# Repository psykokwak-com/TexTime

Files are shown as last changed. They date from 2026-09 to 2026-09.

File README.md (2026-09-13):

# TexTime

TexTime is a DIY word clock: a steel faceplate with the letters cut out, a matrix of
addressable RGB LEDs behind it, and an ESP8266 that tells the time in words, in French
or English. It comes in two sizes, a 40 × 40 cm clock that can be 3D-printed and
assembled at home, and a 100 × 100 cm wall piece built on laser-cut MDF.

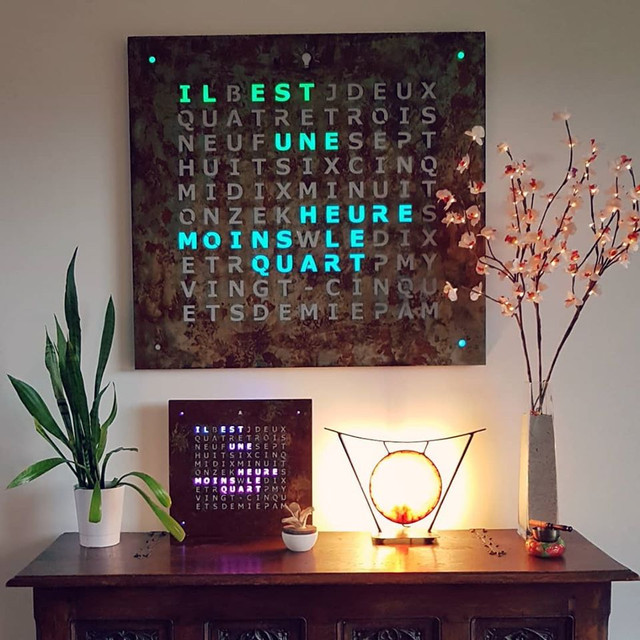
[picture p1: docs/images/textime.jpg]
TexTime


Everything needed to build one is in this repository: the firmware, the electronics,
the mechanical files, the bills of materials and the build guides.

**A word of caution.** This repository gathers, after the fact, the pieces of a project
that is several years old: firmware, design files, notes and photos brought together
into one place. Some of the information may be inaccurate or out of date, in particular
supplier references, part availability, prices and online tools. Check before ordering,
and treat the guides as a starting point rather than a guarantee.

## What is in here

| Folder | Content |
|---|---|
| [`firmware/TexTime`](firmware/TexTime) | Arduino sketch for the ESP8266 (NodeMCU). Web interface, MQTT, NTP, scheduler, animations, games. Pre-built binaries are on the [releases page](../../releases). |
| [`hardware/electronics/pcb-multi-ledstripe`](hardware/electronics/pcb-multi-ledstripe) | The control board, common to both sizes when the LEDs are a strip: schematic, gerbers, bill of materials, JLCPCB SMT files. |
| [`hardware/electronics/pcb-40x40-integrated`](hardware/electronics/pcb-40x40-integrated) | The 40 × 40 integrated board: one PCB carrying the 114 WS2813 LEDs and the control electronics, instead of a cut-up strip. Both boards can be made at [JLCPCB](https://jlcpcb.com/) for a few euros from the gerber files. |
| [`hardware/mechanical/40x40`](hardware/mechanical/40x40) | Faceplate DXF, 3D-printed frame STL (one piece or four parts), back cover DXF. |
| [`hardware/mechanical/100x100`](hardware/mechanical/100x100) | Faceplate DXF and the three laser-cut MDF layers of the LED support. |
| [`bom`](bom) | Bill of materials for each size, with supplier references (French). |
| [`docs`](docs) | Build guides (French). |

## The two sizes

|  | 40 × 40 | 100 × 100 |
|---|---|---|
| Faceplate | Steel S235, 1 mm, laser cut, held by 24 magnets | Steel S235, 1 mm, laser cut |
| Structure | 3D-printed PLA frame, one piece or four | Five glued laser-cut MDF plates (3 + 3 × 10 + 3 mm), no frame |
| LEDs | Strip, 30 LED/m, 114 LEDs, or the integrated board | Strip, two LEDs per letter, folded at the end of each row |
| Control | Control board with the strip; with the integrated board it is already on it, nothing extra to make | Control board |
| Power | 5 V 5 A | 5 V 10 A |
| Firmware "Clock type" | `40x40@1` | `100x100@3` (folded strip), `@2` or `@1` (cut and joined) |

For the strip, SK6812 RGBW 5 V is the better choice today: better quality than
WS2812/WS2813, and its dedicated white LED is used for white text. WS2813 still works.
The strip type is selected in the settings, "LED type".

## Building one

1. Read the build guide: [`docs/build-guide-40x40.md`](docs/build-guide-40x40.md) or [`docs/build-guide-100x100.md`](docs/build-guide-100x100.md).
2. Order the parts from the bill of materials in [`bom`](bom).
3. Flash the latest firmware from the [releases](../../releases), or build it yourself, see [`firmware/TexTime/README.md`](firmware/TexTime/README.md).
4. On first boot the clock opens a `TexTime-xxxx` WiFi network; connect to it, open `http://192.168.1.1/` and enter your WiFi settings.

This is a personal project, shared so that others can build their own. It comes without
any guarantee.

## License

Everything here, firmware, hardware files, documentation and images, is released under
[CC0 1.0 Universal](LICENSE): public domain, no rights reserved, no attribution
required. Use it, change it, sell it. TexTime is itself a reproduction of an existing
word-clock design, and no ownership is claimed on the idea.

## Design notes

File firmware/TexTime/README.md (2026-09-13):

# TexTime

TexTime project is a DIY word clock project based on an ESP8266 MCU and WS2813 LEDs. 
The clock displays time using illuminated words rather than traditional digits, with several features like : 
- Support for multiple languages (French and English).
- Web interface configuration
- MQTT support
- Automatic NTP time synchronization with timezone and daylight saving
- Multiple matrix configurations (40x40, 100x100 variants)
- Selectable LED type: WS2812/WS2813 (default), SK6812 RGB and RGBW, WS2811, APA106
- Animation effects: Blink, Fire, Matrix, Rainbow, and more
- Color randomization modes
- Automatic brightness based on ambient light
- OTA firmware update

TexTime

## 👷 Build Requirements

To build this code, you need the following Arduino libraries:
- **NeoPixelBus by Makuna**: https://github.com/Makuna/NeoPixelBus
- **Rtc by Makuna**: https://github.com/Makuna/Rtc

The hardware (electronics, mechanical files, bills of materials) and the build guides
are in the parent folders of this repository.

## 🤖 Development Credits

The modern web interface redesign and optimization were implemented by **Claude AI** (Anthropic), providing:
- Complete frontend/backend refactoring
- Modern responsive design implementation
- Performance optimization for ESP8266
- Enhanced user experience features
- Comprehensive code cleanup and documentation

---

*TexTime continues to evolve with modern web technologies while maintaining its DIY spirit and Arduino compatibility.*

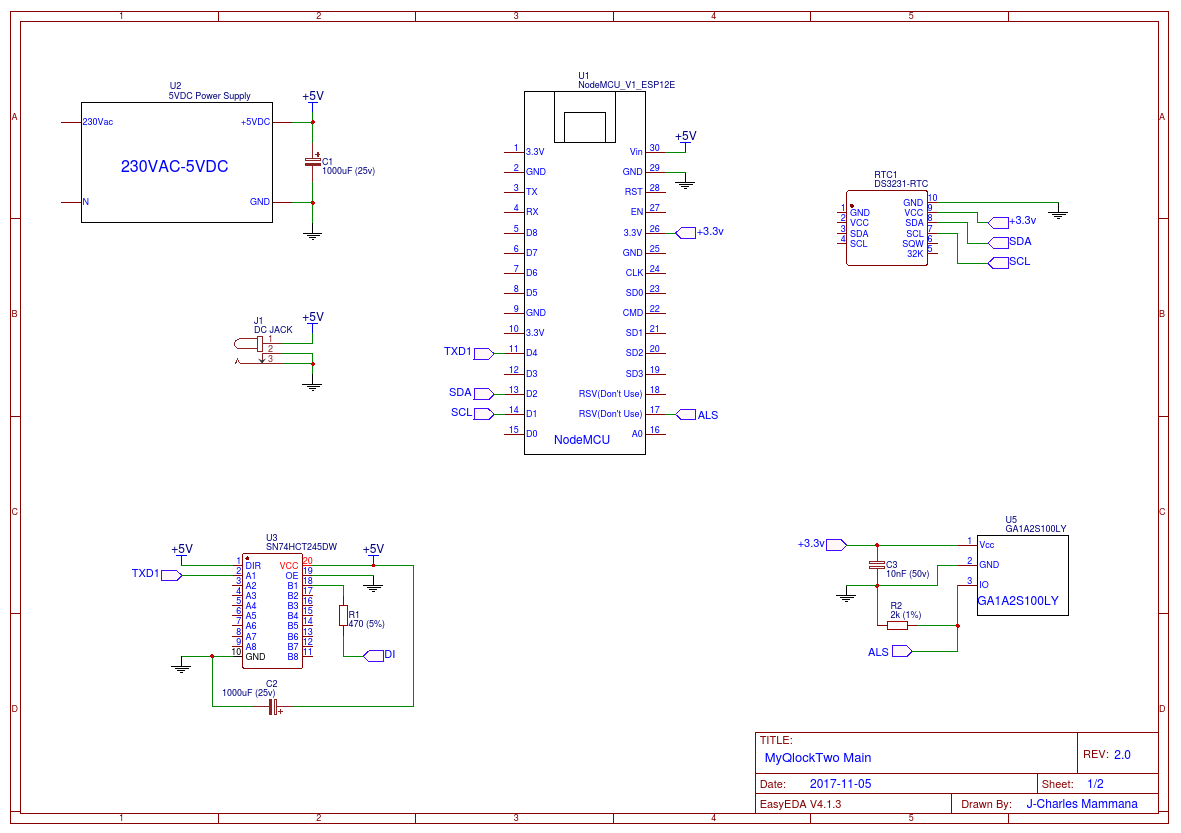
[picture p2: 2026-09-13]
hardware/electronics/pcb-40x40-integrated/schematic-control.png

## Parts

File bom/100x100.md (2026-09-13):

# Nomenclature — TexTime 100 × 100

L'horloge d'un mètre : une façade acier de 90 × 90 cm sur un sandwich de plaques de MDF
collées, sans cadre. Les fichiers de fabrication sont dans
[`hardware/mechanical/100x100`](../hardware/mechanical/100x100), l'électronique est la
même que pour le 40 × 40 en version bandeau. Les quantités de bandeau dépendent du
câblage choisi, voir plus bas.

## Mécanique

| Pièce | Qté | Fichier | Fabrication |
|---|---|---|---|
| Façade acier S235, 1 mm, découpe laser | 1 | [`faceplate-steel-s235-1mm.dxf`](../hardware/mechanical/100x100/faceplate-steel-s235-1mm.dxf) | Sous-traitant découpe laser grand format |
| Plaque avant, MDF 3 mm | 1 | [`led-support-layer0-mdf-3mm.dxf`](../hardware/mechanical/100x100/led-support-layer0-mdf-3mm.dxf) | Découpe laser grand format |
| Plaque intermédiaire, MDF 10 mm | 3 | [`led-support-layer1-mdf-10mm.dxf`](../hardware/mechanical/100x100/led-support-layer1-mdf-10mm.dxf) | Idem, trois exemplaires du même dessin |
| Plaque arrière, MDF 3 mm | 1 | [`led-support-layer2-mdf-3mm.dxf`](../hardware/mechanical/100x100/led-support-layer2-mdf-3mm.dxf) | Idem |
| Vue d'ensemble des plaques assemblées | | [`led-support-assembly.stl.zip`](../hardware/mechanical/100x100/led-support-assembly.stl.zip) | Pour visualiser, pas pour fabriquer |
| Colle à bois | | | Collage des cinq plaques |
| Aimants néodyme N52 | Un lot | | Aliexpress |
| Diffuseur (papier sulfurisé ou calque) | | | |

## Électronique

| Pièce | Qté | Détail |
|---|---|---|
| Carte de contrôle et ses composants | 1 | Identique au 40 × 40, voir [`bom/40x40.md`](40x40.md), section Carte de contrôle |
| Bandeau SK6812 RGBW 5 V, 30 LED/m, IP30 | 2 rouleaux de 5 m | Recommandé. Un bandeau WS2813 convient aussi. Voir le nombre de LED ci-dessous |
| Câble 4 fils | 5 m | Seulement pour les câblages à sections coupées |
| Alimentation 5 V 10 A | 1 | Deux fois plus de LED qu'en 40 × 40 |
| Pile CR2032 | 1 | Pour la RTC |

## Nombre de LED selon le câblage

Le firmware connaît trois câblages pour cette taille, choisis dans « Type d'horloge ».
Le bandeau parcourt les lignes en boustrophédon.

| Type d'horloge | Câblage | LED par lettre | LED au total | Bandeau à 30 LED/m |
|---|---|---|---|---|
| `100x100@3` | Bandeau plié en bout de ligne, sans découpe ni raccord, 4 LED sacrifiées par pli. Recommandé | 2 | 262 | 8,8 m |
| `100x100@2` | Bandeau coupé à chaque ligne, sections raccordées par câble, 2 LED inutilisées entre deux lignes | 2 | 244 | 8,2 m |
| `100x100@1` | Bandeau coupé à chaque ligne, sections raccordées par câble, 1 LED inutilisée entre deux lignes | 1 | 234 | 7,8 m |

Le détail des index de chaque lettre est dans
[`LedStrip.h`](../firmware/TexTime/LedStrip.h), classes `LedConfiguration100x100_1`, `_2` et `_3`.

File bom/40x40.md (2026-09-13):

# Nomenclature — TexTime 40 × 40

Tout ce qu'il faut acheter ou faire fabriquer pour une horloge de 40 cm. Les fichiers
de fabrication sont dans [`hardware/`](../hardware). Les références Aliexpress changent
souvent : chercher l'équivalent si une option n'existe plus.

## Mécanique

| Pièce | Qté | Fichier | Fabrication |
|---|---|---|---|
| Façade acier S235, 1 mm, découpe laser ou jet d'eau | 1 | [`faceplate-steel-1mm.dxf`](../hardware/mechanical/40x40/faceplate-steel-1mm.dxf) | Sous-traitant découpe laser : John Steel, Laserhub, société locale (cherchez sur google)… Variante 2 mm : [`faceplate-steel-2mm.dxf`](../hardware/mechanical/40x40/faceplate-steel-2mm.dxf) |
| Structure imprimée 3D, PLA, remplissage 20 %, couche 0,3 mm | 1 | [`frame-3dprint-one-piece.stl.zip`](../hardware/mechanical/40x40/frame-3dprint-one-piece.stl.zip) ou les quatre parties [`frame-3dprint-part1..4.stl`](../hardware/mechanical/40x40) | Plateau 40 × 40 cm minimum pour la version une pièce, sinon les quatre parties et de la colle PVC |
| Capot arrière MDF 3 mm, découpe laser | 1 | [`back-cover-mdf-3mm.dxf`](../hardware/mechanical/40x40/back-cover-mdf-3mm.dxf) | Artisan laser, ou impression 3D avec [`back-cover.stl`](../hardware/mechanical/40x40/back-cover.stl) |
| Aimants néodyme N52, cylindriques Ø 12 × 3 mm | 24 | | Aliexpress |
| Papier sulfurisé (diffuseur) | 1 feuille 38 × 38 cm | | Cuisine |

## Carte de contrôle — `pcb-multi-ledstripe`

Une seule carte, qui pilote le bandeau de LED. Fichiers dans
[`hardware/electronics/pcb-multi-ledstripe`](../hardware/electronics/pcb-multi-ledstripe).

| Pièce | Repère | Qté | Référence | Fournisseur |
|---|---|---|---|---|
| PCB, 2 couches, blanc conseillé | | 1 (min. 5 à la commande) | [`gerber.zip`](../hardware/electronics/pcb-multi-ledstripe/gerber.zip) | [JLCPCB](https://jlcpcb.com/) : envoyer le zip, les 5 pièces reviennent à quelques euros |
| NodeMCU V3 (ESP-12E) | U1 | 1 | LCSC C111436 | Aliexpress, LCSC |
| Module RTC DS3231 avec AT24C32, montage vertical | RTC1 | 1 | | Aliexpress |
| Pile CR2032 pour la RTC | | 1 | | |
| SN74HCT245N, DIP20 | U3 | 1 | LCSC C133640 | LCSC, RS |
| Condensateur 1000 µF 25 V, Ø 10 mm | C1, C2 | 2 | LCSC C10750 | LCSC, Aliexpress |
| Condensateur 47 µF | C3 | 1 | Nichicon UTS0J470MDD, LCSC C308860 | LCSC |
| Résistance 470 Ω 1 % axiale | R1 | 1 | LCSC C58592 | LCSC, RS |
| Résistance 2,5 kΩ 1 % axiale | R2 | 1 | LCSC C172683 | LCSC, RS |
| Capteur de lumière BH1620FVC-TR, CMS WSOF-5 | U4 | 1 | ROHM, LCSC C84991 | LCSC. Seul composant CMS, soudé côté cuivre ; JLCPCB peut le poser avec [`jlcpcb-smt-bom.csv`](../hardware/electronics/pcb-multi-ledstripe/jlcpcb-smt-bom.csv) et [`jlcpcb-smt-cpl.csv`](../hardware/electronics/pcb-multi-ledstripe/jlcpcb-smt-cpl.csv) |
| Bornier vissable 2 pôles 5,08 mm | CN2 | 1 | Phoenix MKDS3/2-5.08, LCSC C89120 | LCSC, Aliexpress |
| Bornier vissable 4 pôles 5,08 mm | JP1 | 1 | Phoenix MKDS3/4-5.08, LCSC C90087 | LCSC, Aliexpress |

La liste au format CSV, telle qu'exportée d'EasyEDA :
[`bom.csv`](../hardware/electronics/pcb-multi-ledstripe/bom.csv).

## LED — option 1, le bandeau

| Pièce | Qté | Détail |
|---|---|---|
| Bandeau SK6812 RGBW 5 V, 30 LED/m, IP30 | 4 m (114 LED) | Recommandé : meilleure qualité que le WS2813, LED blanche dédiée. Aliexpress, option « 4m 30 IP30 » ou « 5m 30 IP30 ». Un bandeau WS2813 convient aussi |
| Câble 4 fils pour relier les sections | 5 m | Aliexpress, option « 5m 4pin cable » |
| Étain, flux, scotch | | Pour les 24 raccords |

## LED — option 2, la carte intégrée `pcb-40x40-integrated`

Remplace à la fois le bandeau et la carte `pcb-multi-ledstripe` : les 114 LED et toute
l'électronique de contrôle sont sur la même carte, il n'y a pas de carte de contrôle à
fabriquer en plus. Fichiers dans
[`hardware/electronics/pcb-40x40-integrated`](../hardware/electronics/pcb-40x40-integrated).

| Pièce | Qté | Détail |
|---|---|---|
| PCB intégré | 1 (min. 5) | [`gerber.zip`](../hardware/electronics/pcb-40x40-integrated/gerber.zip), à faire fabriquer chez [JLCPCB](https://jlcpcb.com/) pour pas cher |
| LED WS2813B-B | 114, prendre 120 | Le suffixe **B-B** compte : c'est le brochage du PCB. TME ou LCSC de préférence |
| Bornier vissable 4 pôles 5,08 mm | 1 | Aliexpress, option « 128-5.08-2P » × 2 |
| Composants de contrôle | 1 jeu | Les mêmes que ceux de la carte de contrôle ci-dessus, soudés sur la carte intégrée, sans le PCB `pcb-multi-ledstripe`. Voir [`schematic-control.png`](../hardware/electronics/pcb-40x40-integrated/schematic-control.png) |

## Alimentation

| Pièce | Qté | Détail |
|---|---|---|
| Bloc secteur 5 V 5 A, prise EU | 1 | Aliexpress. L'horloge tire jusqu'à 5 A |
| Embase DC femelle DC-022B 5,5 × 2,1 mm | 1 | Aliexpress, se fixe sur la structure |

## Visserie

| Pièce | Qté | Usage |
|---|---|---|
| Vis M3 × 12 tête fraisée, inox | 4 | PCB de contrôle sur la structure |
| Écrou nylstop M3, inox | 4 | Idem |
| Vis à bois 3 × 12 | 11 | Capot arrière |
| Colle PVC (gouttières) | | Assemblage des quatre parties de la structure |
| Pistolet à colle | | Aimants, câble d'alimentation |

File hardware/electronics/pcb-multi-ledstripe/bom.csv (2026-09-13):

ID | Name | Designator | Footprint | Quantity | Manufacturer Part | Manufacturer | Supplier | Supplier Part
1 | NodeMCU_V1_ESP12E | U1 | MY NODEMCU | 1 | NodeMCU-32SLua | Ai-Thinker | LCSC | C111436
2 | 1000uF (25v) | C1,C2 | CAP-D10.0XF5.0 | 2 | 1000uF 25V | ValuePro | LCSC | C10750
3 | DS3231-RTC | RTC1 | DS3231-RTC-24C32-EEPROM VERTICAL SIPPY | 1 | ?
4 | SN74HCT245N | U3 | DIP20 | 1 | SN74HCT245N | Texas Instruments | LCSC | C133640
5 | M04 | JP1 | MKDS3/4-5.08 | 1 | MKDS3/4-5.08 | Phoenix Contact | LCSC | C90087
6 | 470 (1%) | R1 | AXIAL-0.3 | 1 | MFR0W4F4700A50 | UniOhm | LCSC | C58592
7 | 2.5k (1%) | R2 | AXIAL-0.3 | 1 | RN16T52501F | TA-I Tech | LCSC | C172683
8 | BH1620FVC-TR | U4 | WSOF-5 | 1 | BH1620FVC-TR | ROHM | LCSC | C84991
9 | MKDS3/2-5.08 | CN2 | MKDS3/2-5.08 | 1 | MKDS3/2-5.08 | Phoenix Contact | LCSC | C89120
10 | 47uF | C3 | CAP-5*7 | 1 | UTS0J470MDD | Nichicon | LCSC | C308860

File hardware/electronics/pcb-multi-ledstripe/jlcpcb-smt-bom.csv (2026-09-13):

ID | Name | Designator | Footprint | Quantity | Manufacturer Part | Manufacturer | Supplier | Supplier Part
0 | BH1620FVC-TR | U4 | WSOF-5 | 1 | BH1620FVC-TR | ROHM | LCSC | C84991

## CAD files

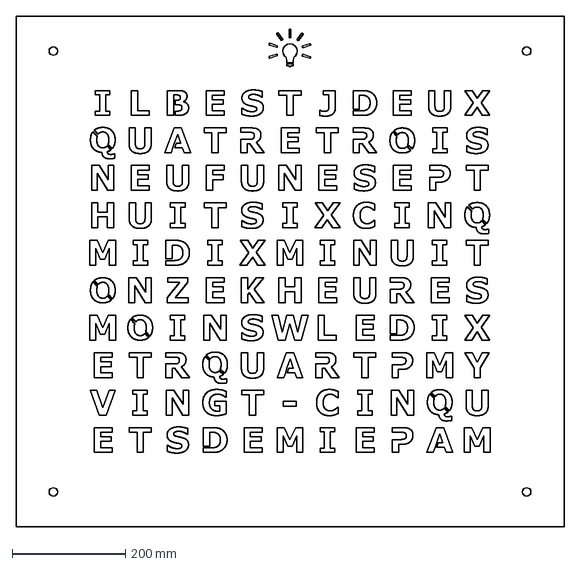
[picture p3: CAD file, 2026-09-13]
hardware/mechanical/100x100/faceplate-steel-s235-1mm.dxf
966.0 x 900.0 mm

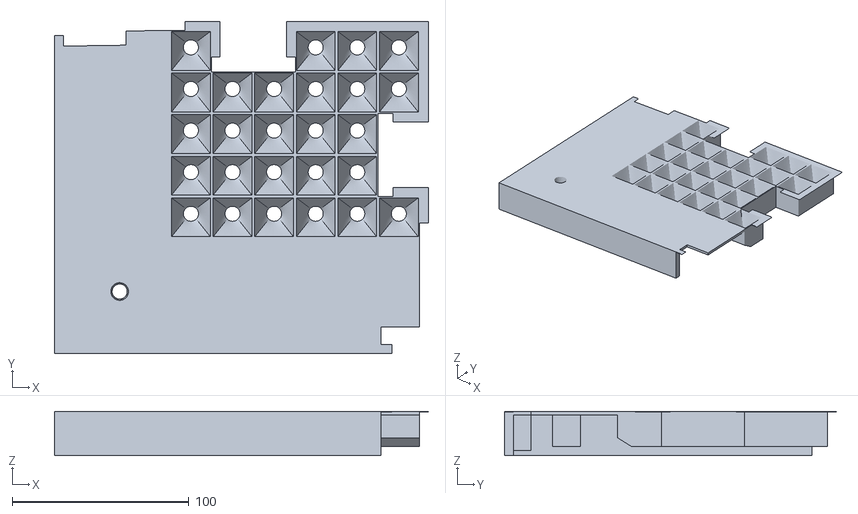
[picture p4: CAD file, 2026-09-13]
hardware/mechanical/40x40/frame-3dprint-part4.stl
211.8 x 187.8 x 25.0

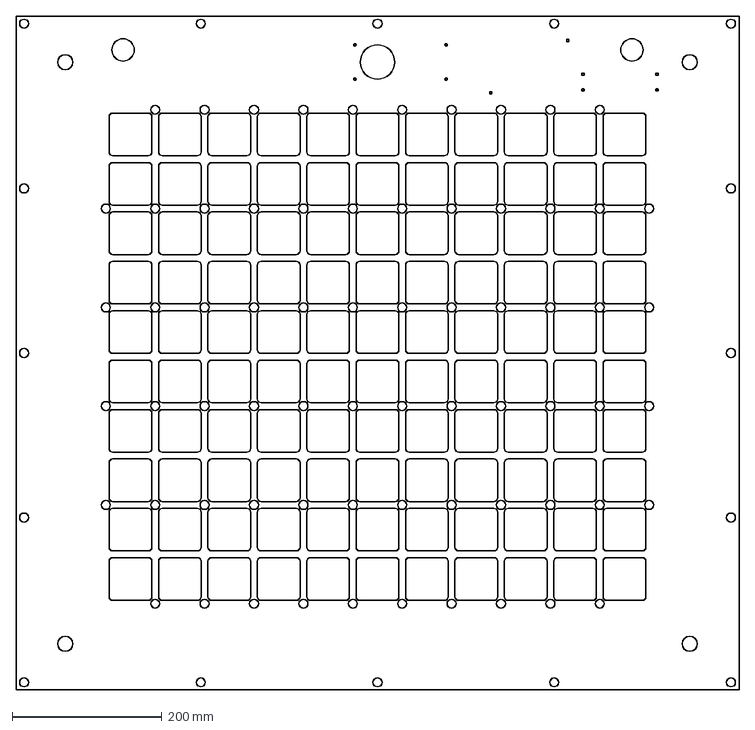
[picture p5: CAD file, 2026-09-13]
hardware/mechanical/100x100/led-support-layer0-mdf-3mm.dxf
966.0 x 900.0 mm

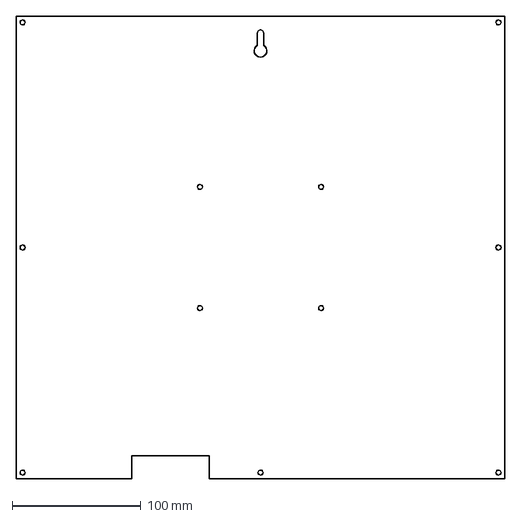
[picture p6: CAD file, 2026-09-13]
hardware/mechanical/40x40/back-cover-mdf-3mm.dxf
379.5 x 359.5 mm

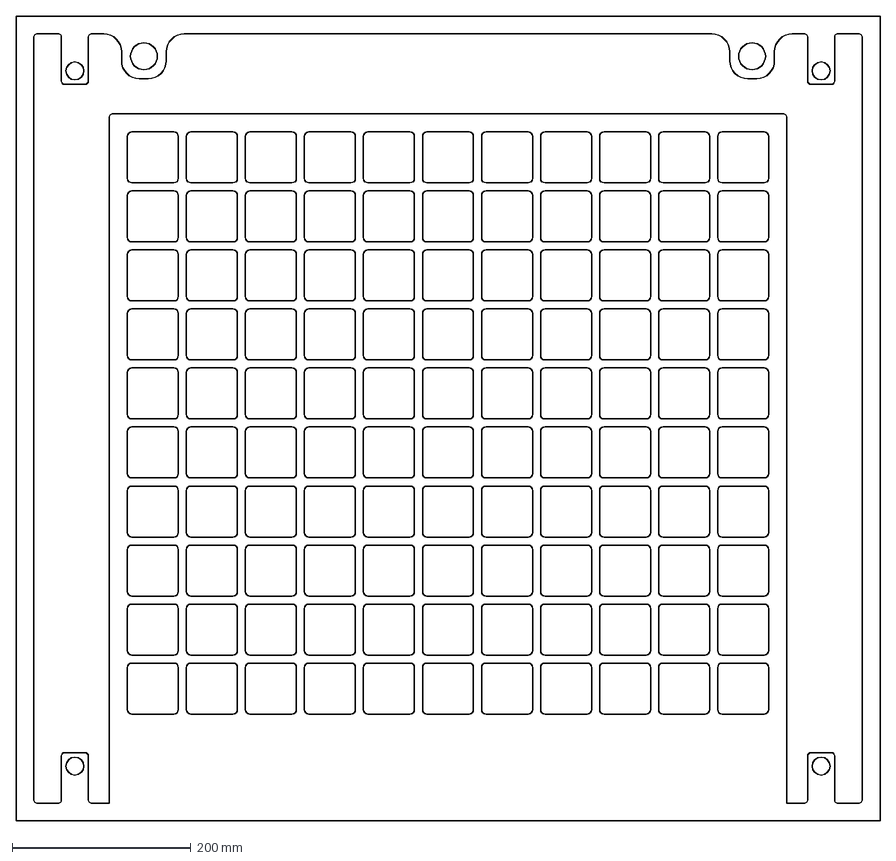
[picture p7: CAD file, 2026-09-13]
hardware/mechanical/100x100/led-support-layer1-mdf-10mm.dxf
966.0 x 900.0 mm

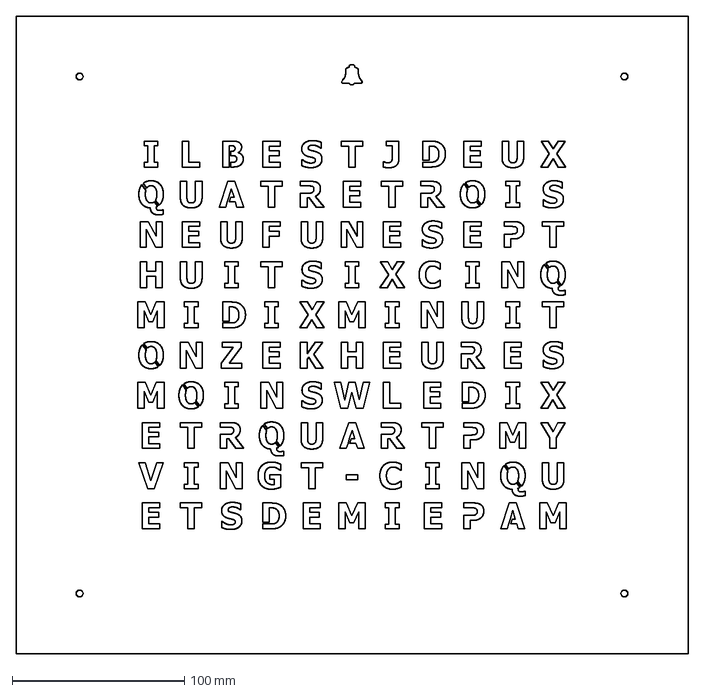
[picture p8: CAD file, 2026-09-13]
hardware/mechanical/40x40/faceplate-steel-1mm.dxf
390.0 x 370.0 mm

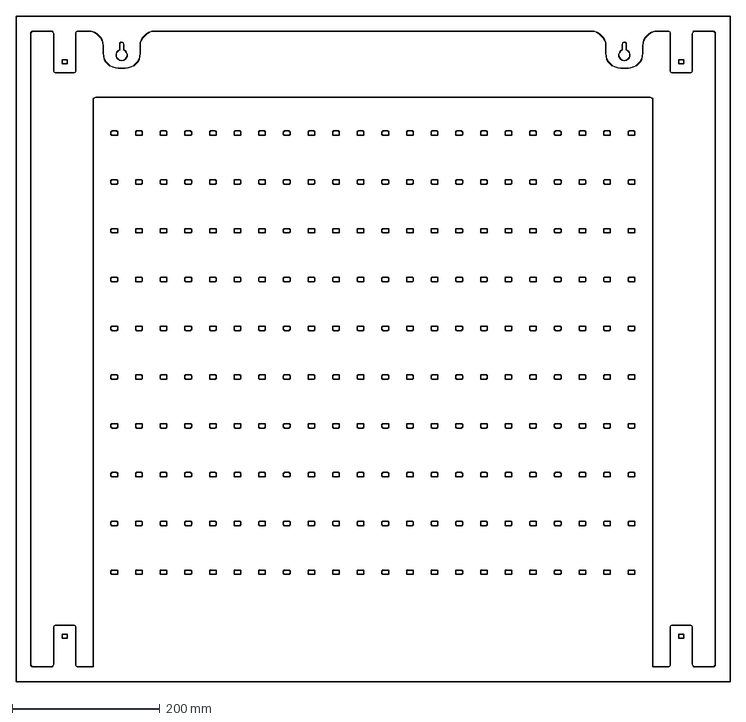
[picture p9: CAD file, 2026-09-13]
hardware/mechanical/100x100/led-support-layer2-mdf-3mm.dxf
966.0 x 900.0 mm

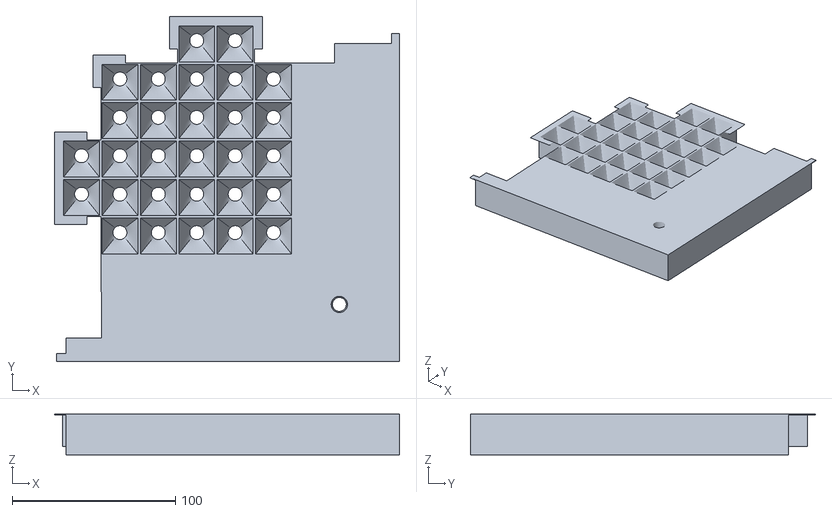
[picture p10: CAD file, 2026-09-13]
hardware/mechanical/40x40/frame-3dprint-part3.stl
211.6 x 211.6 x 25.0

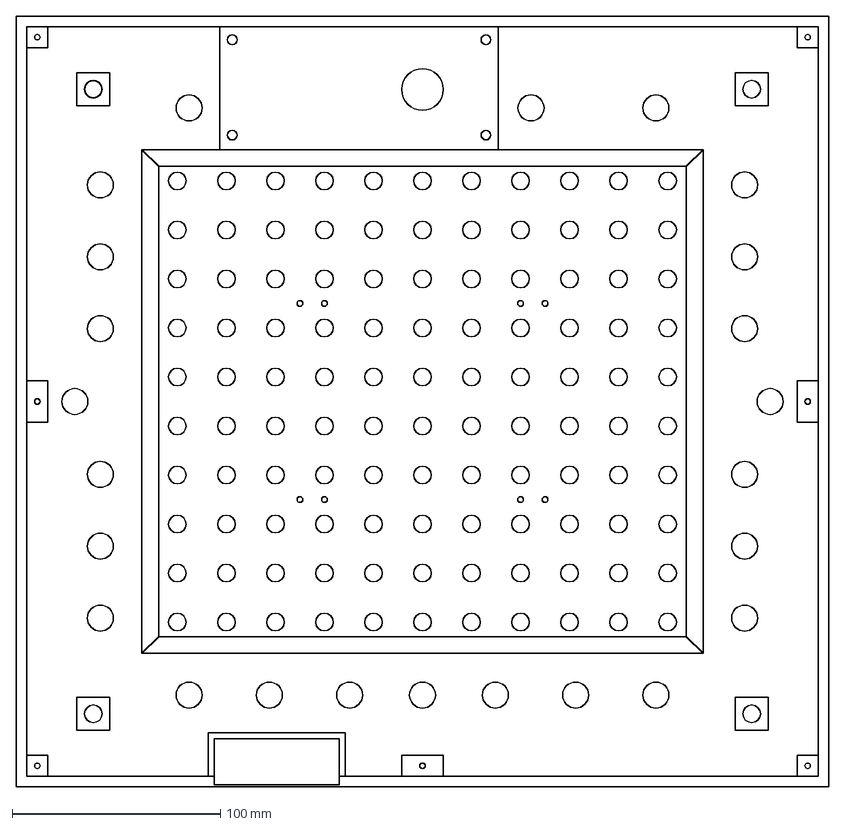
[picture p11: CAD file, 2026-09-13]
hardware/mechanical/40x40/frame-3dprint-outline.dxf
390.0 x 370.0 mm

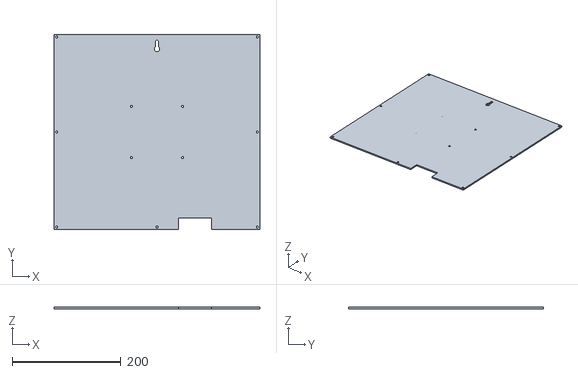
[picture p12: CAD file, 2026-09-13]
hardware/mechanical/40x40/back-cover.stl
379.5 x 359.5 x 3.00

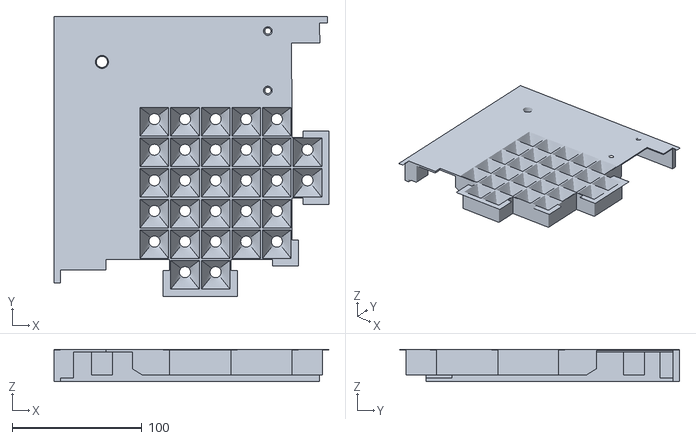
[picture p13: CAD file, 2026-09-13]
hardware/mechanical/40x40/frame-3dprint-part1.stl
211.6 x 215.6 x 25.0

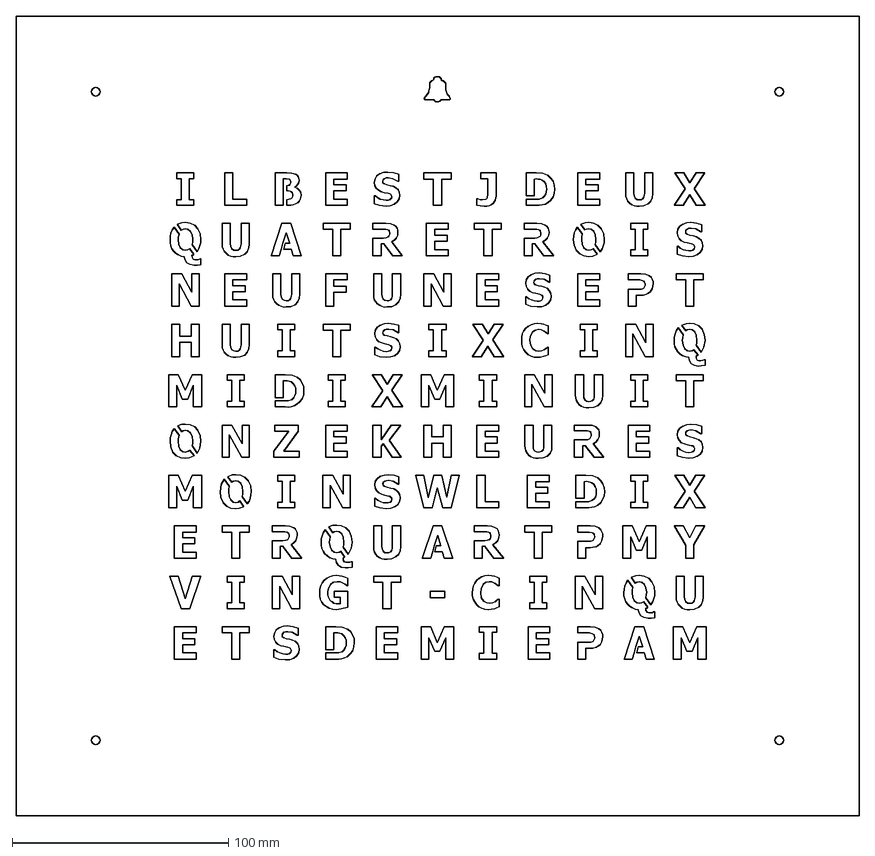
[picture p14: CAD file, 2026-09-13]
hardware/mechanical/40x40/faceplate-steel-2mm.dxf
390.0 x 370.0 mm

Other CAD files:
hardware/mechanical/40x40/frame-3dprint-part2.stl

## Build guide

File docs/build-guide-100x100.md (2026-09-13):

# Fabriquer une TexTime 100 × 100

L'horloge d'un mètre. Elle reprend l'électronique du 40 × 40 en version bandeau ; la
mécanique change entièrement : pas de cadre ni d'impression 3D, la structure est un
sandwich de plaques de MDF découpées au laser et collées, sur lequel vient la façade.

Ce guide décrit les fichiers disponibles et les différences avec le 40 × 40. Pour tout
ce qui est commun, se reporter au [guide 40 × 40](build-guide-40x40.md).

Nomenclature : [`bom/100x100.md`](../bom/100x100.md).

## 1. La façade

Acier S235 de 1 mm, 90 × 90 cm, découpée au laser :
[`faceplate-steel-s235-1mm.dxf`](../hardware/mechanical/100x100/faceplate-steel-s235-1mm.dxf).
Même démarche qu'au chapitre 1 du guide 40 × 40, mais à cette taille il faut un
sous-traitant équipé en grand format, et la pièce se fait livrer. Finition rouillée et
vernie, ou peinte, comme pour le 40 × 40.

## 2. La structure

Cinq plaques de MDF découpées au laser, empilées et collées, forment la structure
complète : elles portent les LED, forment les alvéoles derrière chaque lettre et
reçoivent la façade. Trois dessins, dont un découpé en trois exemplaires :

| Position | Plaque | Épaisseur | Fichier |
|---|---|---|---|
| Avant, côté façade | couche 0 | 3 mm | [`led-support-layer0-mdf-3mm.dxf`](../hardware/mechanical/100x100/led-support-layer0-mdf-3mm.dxf) |
| Milieu, × 3 | couche 1 | 10 mm | [`led-support-layer1-mdf-10mm.dxf`](../hardware/mechanical/100x100/led-support-layer1-mdf-10mm.dxf) |
| Arrière | couche 2 | 3 mm | [`led-support-layer2-mdf-3mm.dxf`](../hardware/mechanical/100x100/led-support-layer2-mdf-3mm.dxf) |

Soit 1 + 3 × 1 + 1 plaques, 36 mm d'épaisseur au total. L'assemblage, pour se
représenter l'ensemble :
[`led-support-assembly.stl.zip`](../hardware/mechanical/100x100/led-support-assembly.stl.zip).

Coller les plaques les unes sur les autres en les alignant sur leurs découpes, sous
presse ou sous poids le temps du séchage.

## 3. L'électronique

Le circuit de contrôle est la carte `pcb-multi-ledstripe`, sans changement : voir le
chapitre 3.1 du [guide 40 × 40](build-guide-40x40.md#31-le-circuit-de-contrôle).

### 3.1 Le bandeau

Privilégier un bandeau **SK6812 RGBW 5 V**, 30 LED/m, IP30 : de meilleure qualité que
les WS2812/WS2813, avec une LED blanche dédiée que le firmware utilise pour le texte
blanc. Un bandeau WS2813 fonctionne aussi. Dans les deux cas, le type se choisit dans
les paramètres généraux, « Type de LED ».

Le bandeau parcourt les dix lignes de lettres en boustrophédon, deux LED par lettre. Le
firmware connaît trois câblages, à choisir dans « Type d'horloge » :

| Type d'horloge | Câblage | LED par lettre | LED au total |
|---|---|---|---|
| `100x100@3` | **Bandeau plié** en bout de ligne pour repartir sur la suivante. Aucune découpe, aucun raccord ; les 4 LED du pli restent éteintes. Le plus rapide à assembler, recommandé. | 2 | 262 |
| `100x100@2` | Bandeau coupé à chaque ligne, sections reliées par câble ; 2 LED inutilisées entre deux lignes | 2 | 244 |
| `100x100@1` | Bandeau coupé à chaque ligne, sections reliées par câble ; 1 LED inutilisée entre deux lignes | 1 | 234 |

Avec le câblage plié, il faut environ 8,8 m de bandeau à 30 LED/m, soit deux rouleaux
de 5 m. L'ordre exact des LED de chaque câblage est dans
[`LedStrip.h`](../firmware/TexTime/LedStrip.h), classes `LedConfiguration100x100_1`, `_2` et `_3`.

### 3.2 L'alimentation

Avec deux fois plus de LED qu'en 40 × 40, l'alimentation passe à 5 V 10 A. Reboucler le
+5 V et le GND en fin de bandeau est encore plus nécessaire sur cette longueur.

## 4. Firmware, assemblage, mise en route

Identiques au 40 × 40, chapitres 4 à 6 du [guide](build-guide-40x40.md). Deux
différences dans les paramètres généraux : « Type d'horloge » sur le câblage
`100x100@…` correspondant au bandeau posé, et « Type de LED » sur le bandeau choisi.

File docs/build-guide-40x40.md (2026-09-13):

# Fabriquer une TexTime 40 × 40

L'horloge de 40 cm de côté, sans cadre, à façade aimantée. Le montage se fait en six
étapes : la façade, la structure, l'électronique, le firmware, l'assemblage, la mise en
route. Plusieurs chapitres proposent deux approches, à choisir selon l'outillage et le
budget. Le résultat à obtenir :

TexTime 40 × 40

Nomenclature complète : [`bom/40x40.md`](../bom/40x40.md).

## 1. La façade

La façade est une plaque d'acier d'un millimètre, découpée au laser ou au jet d'eau.
Elle vient s'aimanter sur la structure.

### 1.1 Conception

Il faut un fichier DXF, le dessin de la façade.

- **Option 1 : le DXF prêt à l'emploi.** La façade TexTime, en français :
  [`hardware/mechanical/40x40/faceplate-steel-1mm.dxf`](../hardware/mechanical/40x40/faceplate-steel-1mm.dxf).
  Le plan coté est dans [`faceplate-drawing.pdf`](../hardware/mechanical/40x40/faceplate-drawing.pdf).
  Une variante pour de l'acier de 2 mm existe :
  [`faceplate-steel-2mm.dxf`](../hardware/mechanical/40x40/faceplate-steel-2mm.dxf).
- **Option 2 : dessiner la sienne.** Pour une autre langue, une autre police ou un
  autre style de lettres, partir du DXF fourni dans un logiciel de dessin vectoriel ou
  de CAO et ne remplacer que les lettres. Les dimensions de la plaque, les trous et
  l'entraxe de la grille de 11 × 10 lettres et des 4 points de coin doivent rester
  ceux de la façade originale, sinon les lettres ne tombent plus en face des LED. Une
  police « stencil » évite que les intérieurs des lettres fermées, comme le O ou le A,
  ne tombent à la découpe. Le firmware ne connaît que le français et l'anglais ; une
  autre langue demande d'ajouter sa grille dans
  [`textime.h`](../firmware/TexTime/textime.h).

### 1.2 Fabrication

Sans découpeuse laser capable de couper l'acier, il faut passer par un professionnel.
C'est simple et peu coûteux. Une recherche « découpe laser » donne de nombreuses
entreprises ; par exemple :

- https://www.john-steel.com/fr/dxf
- https://laserhub.com/fr
- une société locale, trouvée sur Google

Envoyer un mail avec le DXF en pièce jointe en demandant un devis pour une découpe dans
de l'acier S235 de 1 mm, quantité 1. Comparer plusieurs devis, et privilégier une
société proche pour aller chercher la pièce et éviter les frais de port. Le règlement se
fait en général par virement.

### 1.3 Finition

L'acier S235 rouille naturellement, ce qui donne un style industriel : de nombreux
tutoriels vidéo expliquent comment accélérer la rouille, à stabiliser ensuite par une
couche de vernis. La façade peut aussi être peinte, soi-même ou par un carrossier.

## 2. La structure

La structure est imprimée en 3D. Elle reçoit l'électronique, les LED, la façade, les
câbles. Tout.

### 2.1 Impression

Deux fichiers STL selon la taille du plateau :

- une seule pièce, plateau de 40 × 40 cm minimum :
  [`frame-3dprint-one-piece.stl.zip`](../hardware/mechanical/40x40/frame-3dprint-one-piece.stl.zip)
  (à dézipper avant d'imprimer) ;
- quatre parties à assembler :
  [`frame-3dprint-part1.stl`](../hardware/mechanical/40x40/frame-3dprint-part1.stl),
  [`part2`](../hardware/mechanical/40x40/frame-3dprint-part2.stl),
  [`part3`](../hardware/mechanical/40x40/frame-3dprint-part3.stl),
  [`part4`](../hardware/mechanical/40x40/frame-3dprint-part4.stl).

Sans imprimante, un service d'impression en ligne fait l'affaire avec le fichier une
pièce. Pour limiter le coût : matériau PLA standard, remplissage 20 %, hauteur de couche
0,3 mm.

Dans tous les cas, orienter la pièce face avant vers le bas : la surface en contact avec
la façade doit être côté plateau.

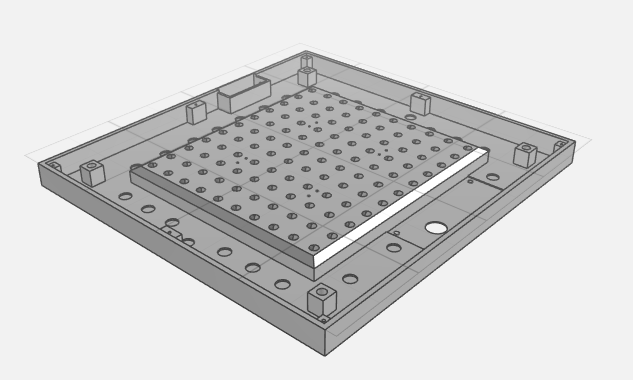
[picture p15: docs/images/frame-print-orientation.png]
Orientation d'impression


### 2.2 Assemblage des quatre parties

Retirer les brims, puis coller les parties à la colle PVC, celle des gouttières. Des
serre-joints aident, sans trop serrer.

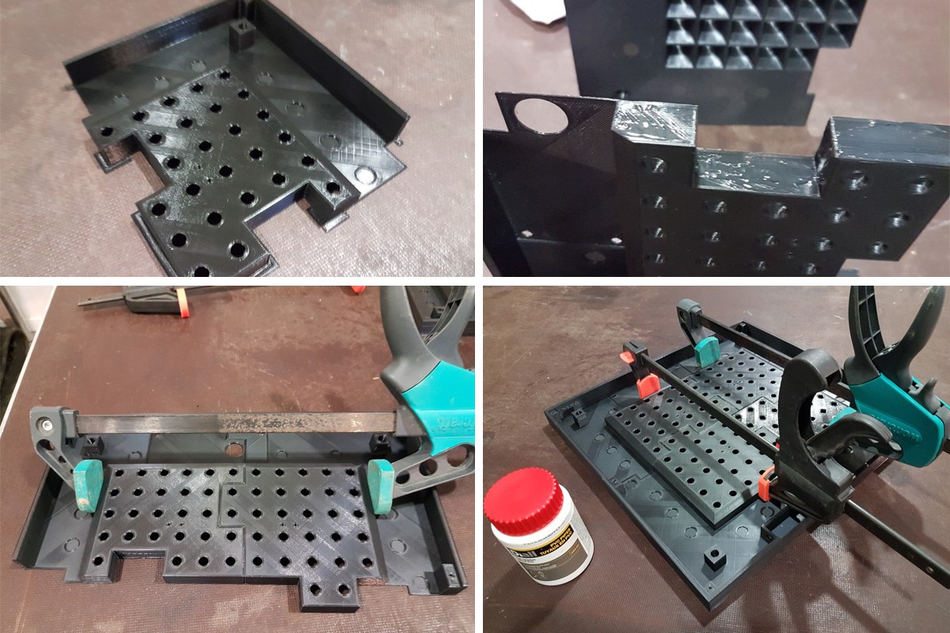
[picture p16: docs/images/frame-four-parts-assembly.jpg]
Assemblage des quatre parties


### 2.3 Les aimants

La façade tient par 24 aimants néodyme, idéalement N52, cylindriques de 12 mm de
diamètre et 3 mm d'épaisseur. Chaque aimant se place dans son logement sur la structure ;
un gros point de pistolet à colle par-dessus le maintient.

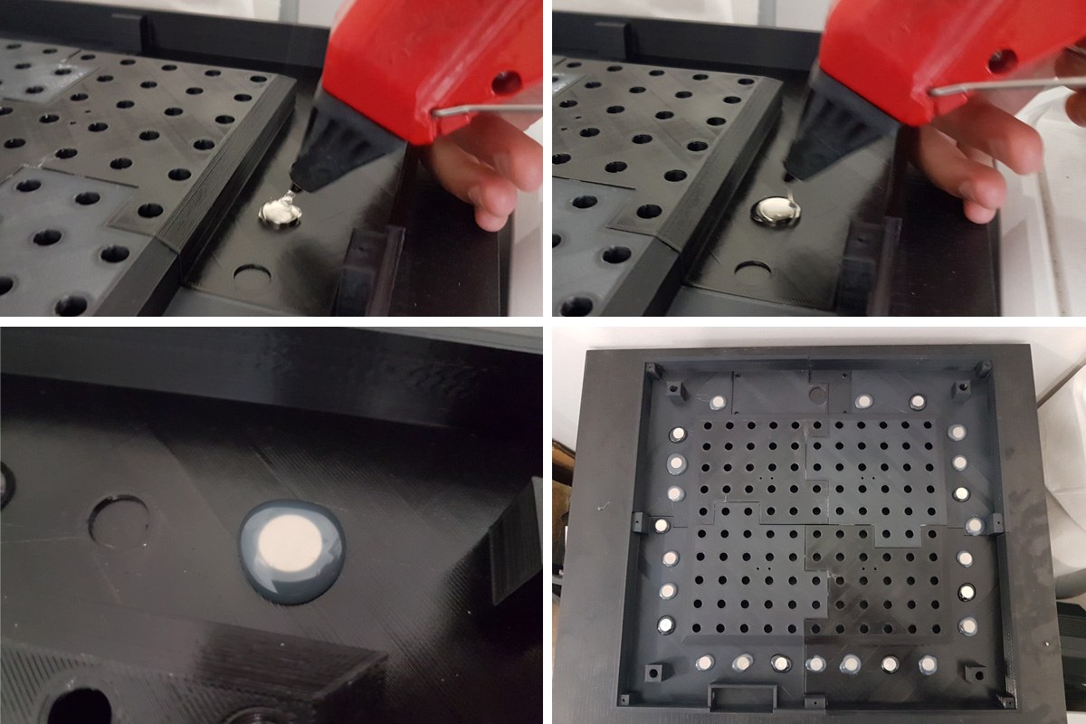
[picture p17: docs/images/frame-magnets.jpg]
Pose des aimants


## 3. L'électronique

Deux parties : le circuit de contrôle, et les LED. Tous les fichiers sont dans
[`hardware/electronics`](../hardware/electronics).

Deux montages possibles, à choisir avant de commander :

- **bandeau de LED** : la carte de contrôle `pcb-multi-ledstripe` (3.1) pilote un
  bandeau découpé et raccordé (3.2, option 1) ;
- **carte intégrée** `pcb-40x40-integrated` : un seul PCB porte les 114 LED et toute
  l'électronique de contrôle (3.2, option 2). Il n'y a alors pas de carte de contrôle à
  fabriquer en plus ; le 3.1 ne sert que pour la liste des composants, qui se soudent
  directement sur la carte intégrée.

### 3.1 Le circuit de contrôle

Il s'articule autour d'un ESP8266 pour le WiFi, d'une RTC pour garder l'heure sans
internet, d'un capteur de luminosité qui adapte l'éclairage à la lumière ambiante, et
d'un adaptateur de niveau qui pilote les LED.

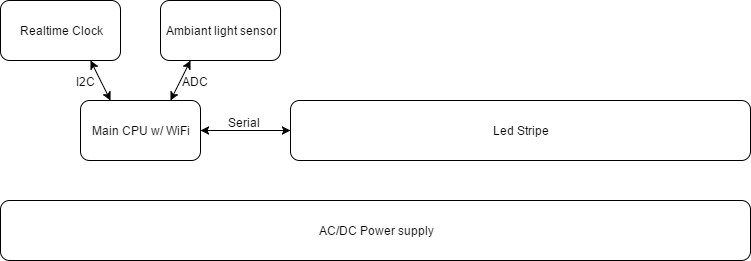
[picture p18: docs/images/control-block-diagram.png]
Synoptique


Tous les composants sont traversants pour être faciles à souder, à l'exception du
capteur de luminosité en CMS, qui demande une bonne dextérité. S'il est absent, l'horloge
fonctionne quand même en luminosité manuelle. JLCPCB peut aussi le poser avec les
fichiers `jlcpcb-smt-*.csv` du dossier.

#### 3.1.1 Le PCB

Faire fabriquer le PCB à partir du dossier gerber
[`pcb-multi-ledstripe/gerber.zip`](../hardware/electronics/pcb-multi-ledstripe/gerber.zip).
[JLCPCB](https://jlcpcb.com/) le fait pour pas cher : créer un compte, faire un devis en
ligne, envoyer le zip. Les paramètres par défaut conviennent ; le blanc est recommandé.
Le minimum est de cinq pièces, pour quelques euros port compris. Même chose pour la
carte intégrée de l'option 2 plus bas.

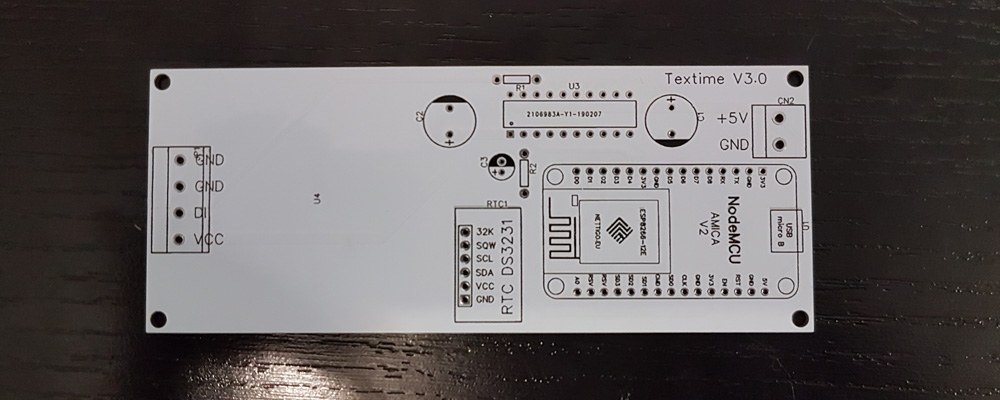
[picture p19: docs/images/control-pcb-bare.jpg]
PCB de contrôle nu


Schéma : [`schematic.png`](../hardware/electronics/pcb-multi-ledstripe/schematic.png).
Rendus : [`pcb-top.png`](../hardware/electronics/pcb-multi-ledstripe/pcb-top.png),
[`pcb-bottom.png`](../hardware/electronics/pcb-multi-ledstripe/pcb-bottom.png).

#### 3.1.2 Soudure

La liste des composants est dans [`bom/40x40.md`](../bom/40x40.md) et dans
[`pcb-multi-ledstripe/bom.csv`](../hardware/electronics/pcb-multi-ledstripe/bom.csv).

- Souder la RTC et les condensateurs de 1000 µF à plat, sinon le circuit est trop haut
  et dépasse de la structure.
- Attention à la polarité des condensateurs.
- Avec cinq PCB et des composants en quantité, plusieurs essais sont possibles.

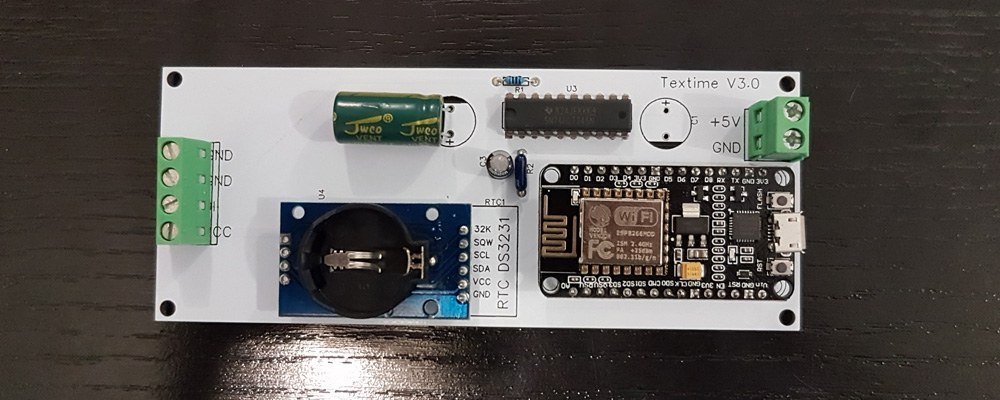
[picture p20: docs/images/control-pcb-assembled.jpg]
PCB de contrôle soudé


#### 3.1.3 Alimentation

L'horloge fonctionne en 5 V et consomme jusqu'à 5 A. Il faut donc un bloc secteur
5 V 5 A, connecté au bornier CN2, sans se tromper de polarité.

Sur Aliexpress, choisir « 5V », « EU Plug », « 5A ». Acheter en même temps l'embase
femelle DC-022B 5,5 × 2,1 mm, qui se fixe sur la structure. Contrôler au multimètre la
position de la masse et du 5 V sur l'embase avant de la câbler.

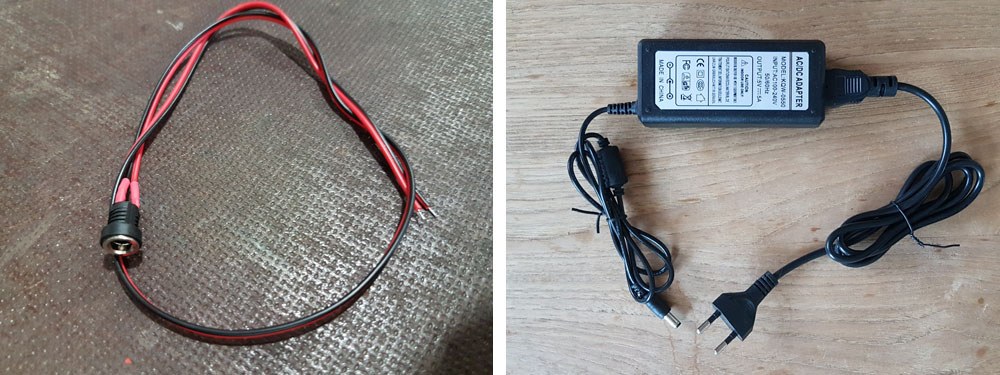
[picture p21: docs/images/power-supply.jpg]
Embase et bloc secteur


### 3.2 Les LED

Deux approches. La première est recommandée pour son coût et sa simplicité.

#### Option 1 : le bandeau de LED

L'horloge compte 110 lettres et 4 points aux coins, soit 114 LED. Il faut un bandeau à
30 LED par mètre, indice IP30 : 4 mètres, donc l'option « 4m 30 IP30 » ou
« 5m 30 IP30 ». Prendre aussi du câble 4 fils pour relier les sections (« 5m 4pin
cable »).

Privilégier un bandeau **SK6812 RGBW 5 V** : de meilleure qualité que les
WS2812/WS2813, avec une LED blanche dédiée que le firmware utilise pour le texte blanc.
Un bandeau WS2813 fonctionne aussi. Dans les deux cas, le type se choisit ensuite dans
les paramètres généraux, « Type de LED ».

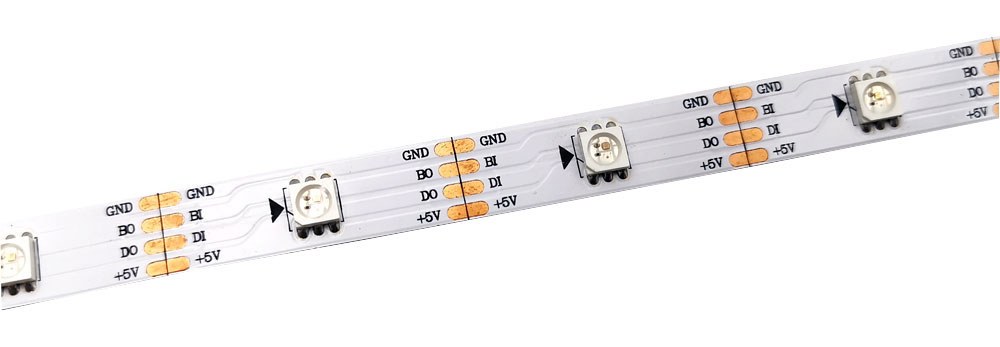
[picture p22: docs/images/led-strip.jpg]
Bandeau WS2813


Le bandeau se coupe entre chaque LED. Des flèches indiquent le sens du signal : il faut
le respecter à chaque raccord. Couper les sections suivantes :

| Longueur de section (LED) | 1 | 2 | 3 | 4 | 5 | 6 | 7 | 8 | 9 | 10 |
|---|---|---|---|---|---|---|---|---|---|---|
| Nombre de sections | 6 | 2 | 2 | 2 | 2 | 2 | 2 | 2 | 2 | 2 |

Les sections se posent en diagonale sur la structure, en partant du coin en haut à
droite de la matrice et en finissant au coin en bas à gauche, dans l'ordre 1, 2, 3 … 10,
10, 9 … 2, 1. Les quatre LED seules restantes vont sur les points 1, 2, 3 et 4 des
coins. Longueur de câble entre chaque section, dans l'ordre du signal, à partir du PCB :

| Raccord | PCB→1 | 1→2 | 2→3 | 3→4 | 4→5 | 5→6 | 6→7 | 7→8 | 8→9 | 9→10 | 10→10 | 10→9 | 9→8 | 8→7 | 7→6 | 6→5 | 5→4 | 4→3 | 3→2 | 2→1 | 1→coin 1 | coin 1→2 | coin 2→3 | coin 3→4 |
|---|---|---|---|---|---|---|---|---|---|---|---|---|---|---|---|---|---|---|---|---|---|---|---|---|
| cm | 25 | 17 | 27 | 37 | 47 | 57 | 67 | 77 | 87 | 97 | 107 | 107 | 97 | 87 | 77 | 67 | 57 | 47 | 37 | 27 | 19 | 135 | 135 | 135 |

Quelques remarques :

- Respecter le sens des flèches d'une section à l'autre.
- Reboucler le +5 V et le GND de la dernière LED sur la première : cela réduit la chute
  de tension le long du ruban, visible sinon en blanc à pleine luminosité.
- Étamer les câbles avec du flux, et mettre de l'étain sur les contacts des sections
  avant de les souder ensemble.

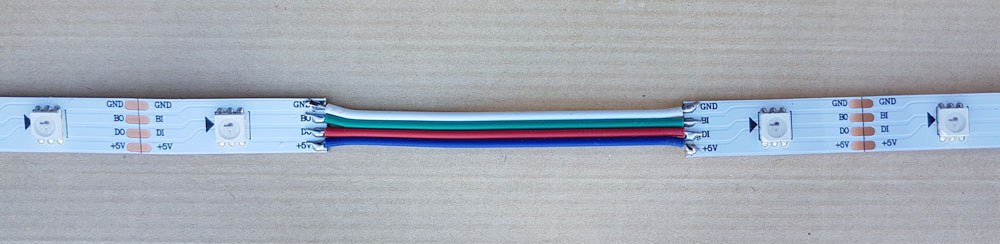
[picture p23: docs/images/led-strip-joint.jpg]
Raccord entre deux sections


L'ordre des LED attendu par le firmware est celui de `LedConfiguration40x40` dans
[`LedStrip.h`](../firmware/TexTime/LedStrip.h).

#### Option 2 : la carte intégrée

Au lieu d'un bandeau, un grand PCB porte les 114 LED et tout le circuit de contrôle :
NodeMCU, RTC, capteur de luminosité, adaptateur de niveau, condensateurs, bornier
d'alimentation. Il remplace donc la carte `pcb-multi-ledstripe`, qu'il n'y a pas à
fabriquer. Plus de découpe ni de raccords, mais 114 LED à souder une à une.

Faire fabriquer le PCB comme au 3.1.1 avec
[`pcb-40x40-integrated/gerber.zip`](../hardware/electronics/pcb-40x40-integrated/gerber.zip). La LED est
la **WS2813B-B**, le suffixe B-B est important : c'est le brochage du PCB. Pour une
autre WS2813, vérifier le brochage sur la datasheet. TME ou LCSC de préférence, 114 plus
quelques-unes de rechange. Un petit triangle sur la LED indique son sens : le coin
biseauté doit correspondre à celui du dessin du PCB. Les composants de contrôle sont
ceux de la liste du 3.1.2, à souder sur cette carte ; le bornier 4 broches y sert au
raccordement de l'alimentation.

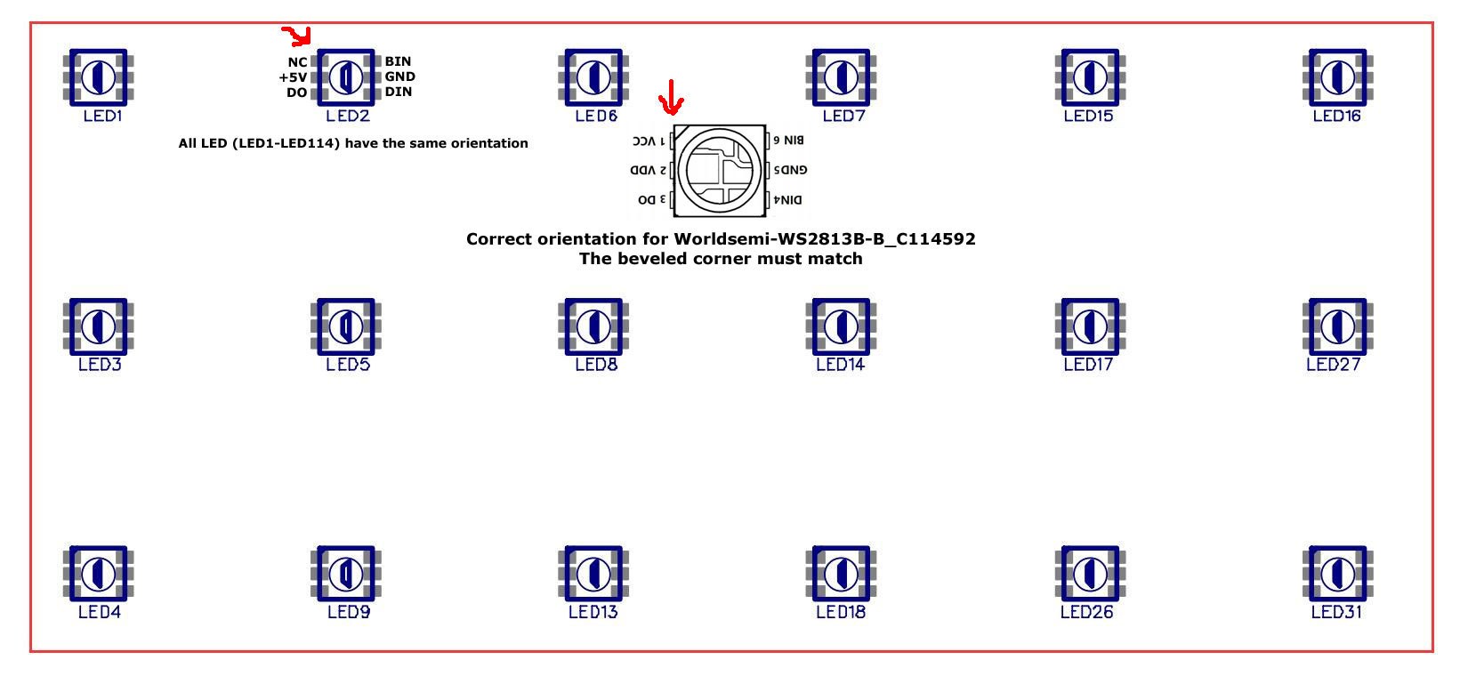
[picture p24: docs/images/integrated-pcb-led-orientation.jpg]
Orientation des LED sur le PCB


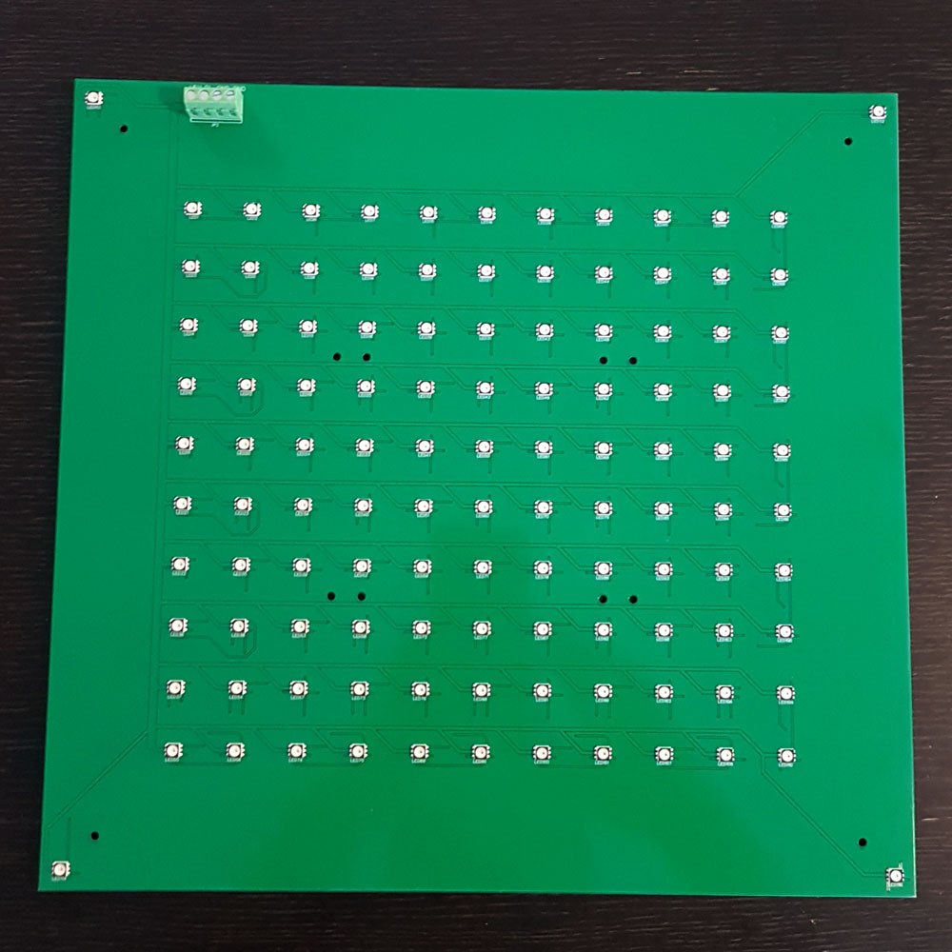
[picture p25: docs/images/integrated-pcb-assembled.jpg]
Carte intégrée soudée


Schémas et rendus dans [`hardware/electronics/pcb-40x40-integrated`](../hardware/electronics/pcb-40x40-integrated),
photos du montage dans [`photos`](../hardware/electronics/pcb-40x40-integrated/photos).

## 4. Le firmware

Le circuit de contrôle repose sur une carte NodeMCU, bâtie sur l'ESP8266, pleinement
supporté par l'environnement Arduino.

Au démarrage, l'horloge charge sa configuration et se connecte au WiFi enregistré. Si
elle ne le trouve pas, ou n'a pas de configuration, elle devient elle-même point
d'accès. On s'y connecte depuis un téléphone ou un ordinateur, on ouvre
`http://192.168.1.1/` et on saisit les paramètres WiFi. Ensuite elle se met à l'heure
seule par NTP.

Il faut d'abord flasher le processeur une première fois :

- **Option 1 : le binaire.** Télécharger `TexTime.bin` sur la
  [page des releases](../../../releases). Brancher le
  NodeMCU en USB, lancer
  [nodemcu-pyflasher](https://github.com/marcelstoer/nodemcu-pyflasher), choisir le
  fichier et le port COM, cliquer « Flash NodeMCU ». Une LED bleue qui clignote à la fin
  signifie que tout s'est bien passé. Les mises à jour suivantes se font depuis
  l'interface web.
- **Option 2 : compiler.** Pour qui connaît Arduino. Installer le support ESP8266 et les
  bibliothèques listées dans
  [`firmware/TexTime/README.md`](../firmware/TexTime/README.md), ouvrir le sketch,
  compiler, flasher. Corrections et nouvelles fonctions sont bienvenues en pull request.

## 5. L'assemblage

### 5.1 Alimentation et circuit de contrôle

Fixer l'embase et le câble d'alimentation sur la structure ; un point de colle chaude
maintient le câble.

Avec le bandeau, fixer ensuite la carte de contrôle par quatre vis M3 × 12 à tête
fraisée et écrous nylstop. Le capteur de luminosité, sur l'autre face du PCB, doit se
trouver exactement au milieu du trou prévu dans la structure. Insérer le câble
d'alimentation dans le bornier : rouge sur +5 V, noir sur GND.

Avec la carte intégrée, il n'y a pas de carte de contrôle à fixer : le câble
d'alimentation ira sur le bornier de la carte intégrée au 5.2.

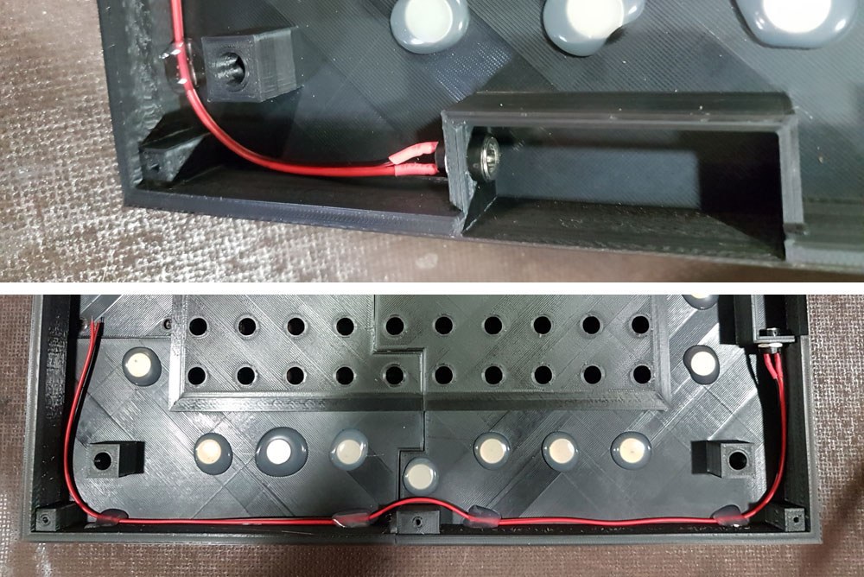
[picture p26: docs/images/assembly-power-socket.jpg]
Embase et câble d'alimentation fixés


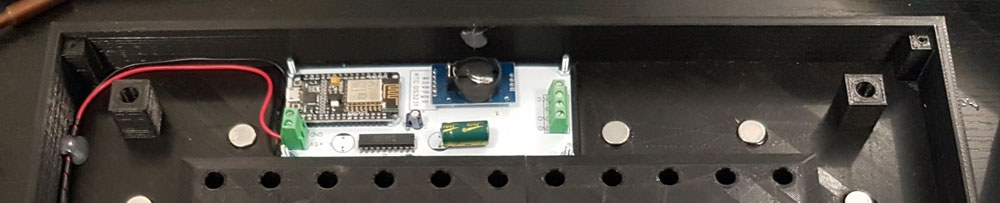
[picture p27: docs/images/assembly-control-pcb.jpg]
Circuit de contrôle fixé


### 5.2 Les LED

- **Bandeau :** poser les sections en diagonale comme décrit au 3.2, du coin en haut à
  droite (début) au coin en bas à gauche (fin), puis les quatre LED des coins dans
  l'ordre 1, 2, 3, 4. Câbler le début du bandeau au bornier du circuit de contrôle en
  respectant l'ordre des fils. Du scotch aide à maintenir le bandeau sur la structure.
- **Carte intégrée :** câbler l'alimentation sur son bornier (rouge sur +5 V, noir sur
  GND), la retourner et la poser dans la structure. Chaque LED doit tomber dans son
  trou, et le capteur de luminosité au milieu du trou prévu pour lui.

Dans les deux cas, mettre la pile CR2032 dans la RTC avant de fermer.

Bandeau posé, du début en haut à droite à la fin en bas à gauche, puis les coins 1 à 4 :

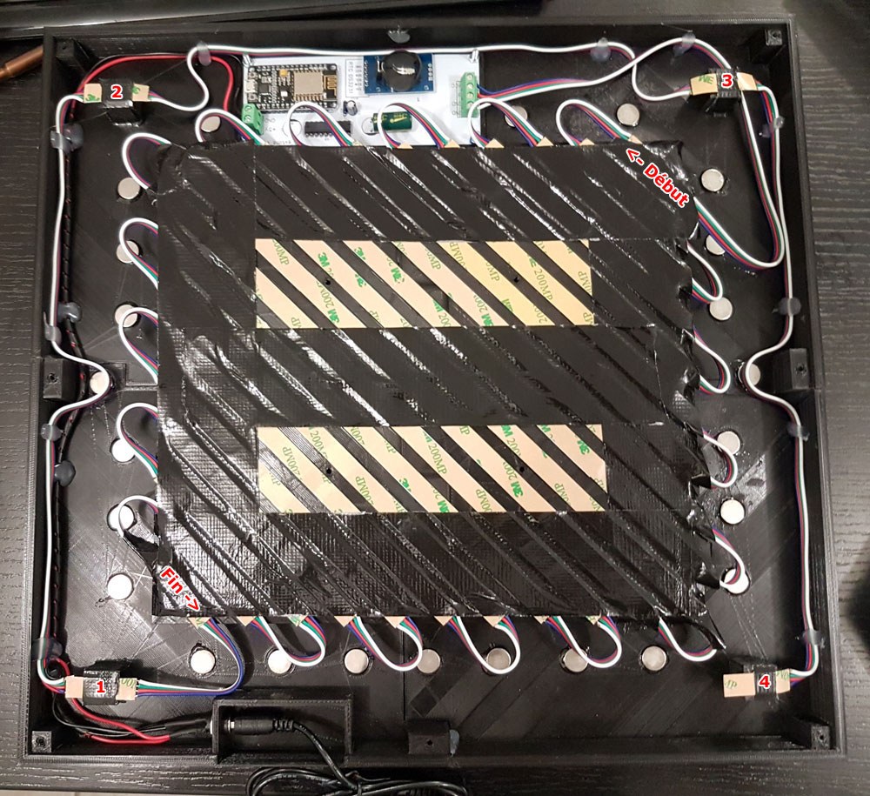
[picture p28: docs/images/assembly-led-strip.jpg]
Bandeau posé sur la structure


Carte intégrée posée dans la structure :

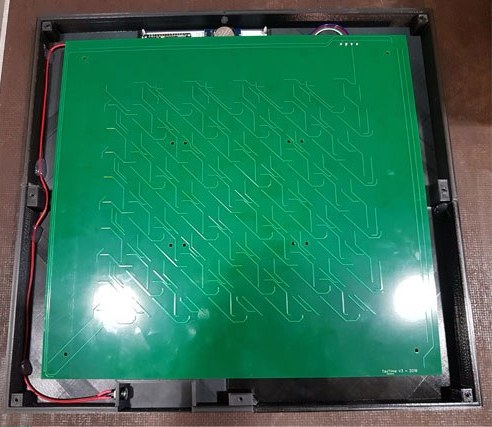
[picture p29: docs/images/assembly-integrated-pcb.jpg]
Carte intégrée posée


### 5.3 Le capot arrière

Le capot solidarise la structure et les LED et donne un aspect fini. Le faire découper
dans du MDF de 3 mm avec
[`back-cover-mdf-3mm.dxf`](../hardware/mechanical/40x40/back-cover-mdf-3mm.dxf), puis le
fixer avec onze vis à bois 3 × 12 mm.

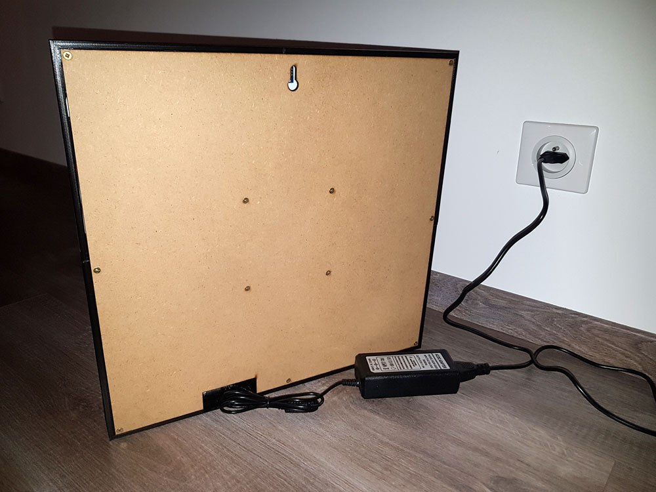
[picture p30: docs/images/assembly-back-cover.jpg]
Capot arrière


### 5.4 La façade

Avant d'approcher la façade, placer un diffuseur : du papier sulfurisé, celui de la
cuisine, dont l'opacité est idéale. En découper un morceau à la taille de la façade moins
1 cm de chaque côté et le scotcher sur la face avant de la structure. Il ne reste qu'à
approcher la façade, qui s'aimante.

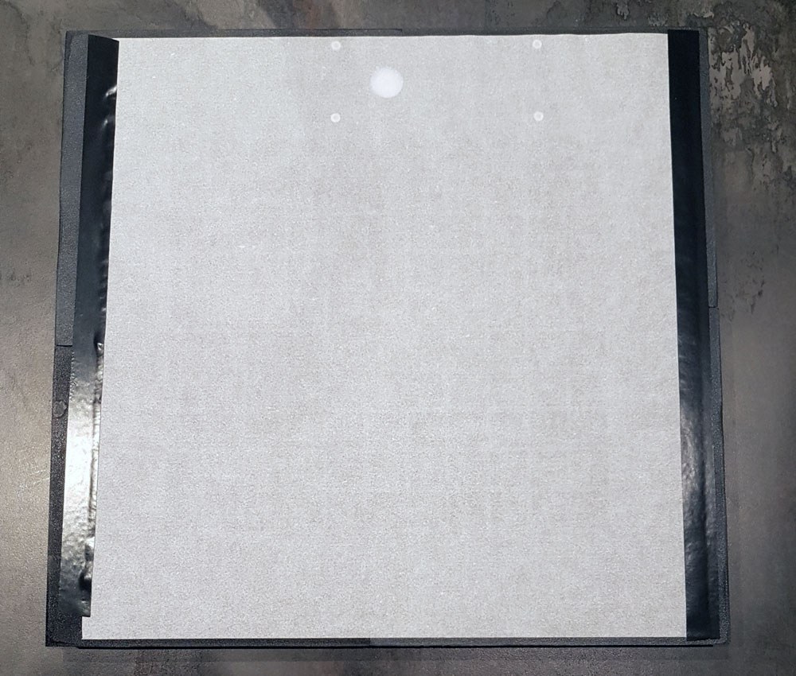
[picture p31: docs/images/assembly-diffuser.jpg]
Diffuseur en papier sulfurisé


## 6. Mise en route

Brancher l'horloge. La première fois, elle n'est pas à l'heure : chercher le réseau WiFi
`TexTime-XXXX`, s'y connecter, ouvrir `http://192.168.1.1/`, et dans les paramètres
réseau entrer son WiFi. Une fois connectée, elle se met à l'heure. On la retrouve
ensuite sur le réseau par son adresse IP ou `http://textime/`. Les paramètres généraux
donnent accès aux couleurs, animations, langues, au type d'horloge et au type de LED :
régler ce dernier sur le bandeau posé, SK6812 ou WS2813, sinon les couleurs sont
fausses.

Pour vérifier le montage, trois modes d'affichage de test :

- **Test Strip** : chaque LED s'allume à tour de rôle dans l'ordre du bandeau, en
  diagonale. Une LED qui reste éteinte est à remplacer.
- **Test Speed** : les LED s'allument le plus vite possible ligne par ligne, de gauche
  à droite ; à chaque tour un des quatre coins s'allume dans le sens horaire. Si ce
  n'est pas ce qui s'affiche, Test Strip dira quelle LED cloche.
- **Test Colors** : toutes les LED passent en rouge, vert, bleu puis blanc. Un défaut de
  couleur en blanc signifie qu'il faut reboucler l'alimentation de la dernière LED sur la
  première.

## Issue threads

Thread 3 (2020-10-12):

OTA not working

ithinkido, 2020-10-12:
I tried today to use the OTA function on the clock to make some changes to the layout, and the esp is not showing up in the Ardiuno upload network port in the OTA section. I have checked with the basic example sketchon the same esp board, and it seems to work and is visible afterward as

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

This is using the example OTA sketch from Arduino on the same board

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

Is there something I need to enable or change to use the OTA feature ?

psykokwak-com, 2020-12-14:
Hello,
I never tried this OTA method. Maybe there is something too old or broken on the OTA update library.
Could you try the HTTP upload OTA upgrade instead ?

Closed 2022-01-22.

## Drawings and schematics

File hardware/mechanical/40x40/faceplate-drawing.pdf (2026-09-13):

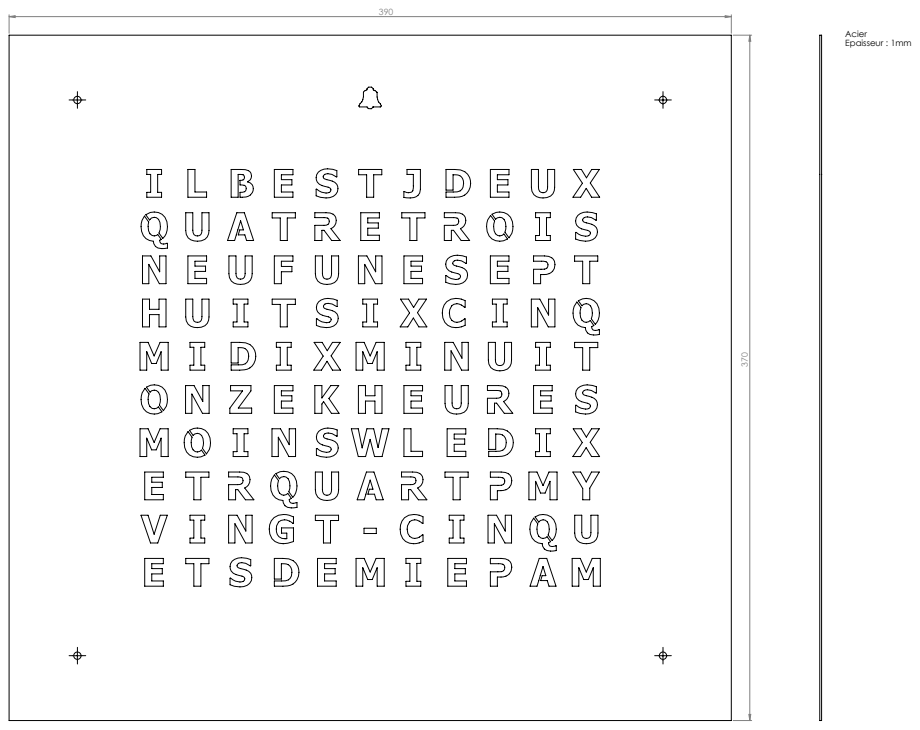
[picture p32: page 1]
Epaisseur : 1mm

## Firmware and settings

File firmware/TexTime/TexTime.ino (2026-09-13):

/*
 * * ESP8266 template with phone config web page
 * based on BVB_WebConfig_OTA_V7 from Andreas Spiess https://github.com/SensorsIot/Internet-of-Things-with-ESP8266
 *
 */
#include <FS.h>
#include <ESP8266WiFi.h>
#include <ESP8266mDNS.h>
#include <ESP8266WebServer.h>
#include <ESP8266HTTPUpdateServer.h>
#include <WiFiUdp.h>
#include <ArduinoOTA.h>
#include <Ticker.h>
#include <EEPROM.h>
#include <DNSServer.h>
#include <NeoPixelBus.h>
#include <NeoPixelBusLg.h>
#include <NeoPixelAnimator.h>
#include <Wire.h>
#include <RtcDS3231.h>
#include <ESP8266SSDP.h>
#include <ESP8266NetBIOS.h>
#include <ESP8266LLMNR.h>

#include "PubSubClient.h"

#include "WiFiMgr.h"
#include "global.h"
#include "mqtt_topics.h"
#include "list.h"
#include "RTC.h"
#include "NTP.h"
#include "LightSensor.h"
#include "LedStrip.h"
#include "mqtt.h"

// Include the HTML, STYLE and Script "Pages"

#include "Page_ico.h"
#include "Page_index.h"
#include "Page_ntp.h"
#include "Page_information.h"
#include "Page_general.h"
#include "Page_network.h"
#include "Page_mqtt.h"
#include "Page_script.js.h"
#include "Page_style.css.h"
#include "Page_scheduler.h"
#include "Page_tetris.h"
#include "Page_snake.h"



extern "C" {
#include "user_interface.h"
}

//*** Normal code definition here ...
void setup() {
  bool CFG_saved = false;

  // No need to set this until option is set in arduino/visualmicro
  //system_update_cpu_freq(SYS_CPU_160MHZ);

  randomSeed(analogRead(ALS_PIN));

  pinMode(LED_BUILTIN, OUTPUT);     // Initialize the LED_BUILTIN pin as an output

  Serial.begin(115200);
  Serial.println("Booting");

  // Config load 
  EEPROM.begin(EEPROM_SIZE); // 1024 for config + 2689 for scheduler (1 enable byte + 336 slots x 8 bytes)
  CFG_saved = ReadConfig();
  if (!CFG_saved)
  {
    // DEFAULT CONFIG
    Serial.println("Set Default config");

    _config.ssid = "";       // SSID of access point
    _config.password = "";   // password of access point
    _config.dhcp = true;
    _config.IP[0] = 192; _config.IP[1] = 168; _config.IP[2] = 1; _config.IP[3] = 100;
    _config.Netmask[0] = 255; _config.Netmask[1] = 255; _config.Netmask[2] = 255; _config.Netmask[3] = 0;
    _config.Gateway[0] = 192; _config.Gateway[1] = 168; _config.Gateway[2] = 1; _config.Gateway[3] = 1;
    _config.DNS[0] = 192; _config.DNS[1] = 168; _config.DNS[2] = 1; _config.DNS[3] = 1;
    _config.DeviceName = "TexTime";

    _config.ntpServerName = "0.ch.pool.ntp.org"; // to be adjusted to PT ntp.ist.utl.pt
    _config.Update_Time_Via_NTP_Every = 86400;
    _config.timeZone = 10;
    _config.isDayLightSaving = true;

    _config.brightnessAuto = true;
    _config.brightness = 128; // [0:255]
    _config.brightnessAutoMinDay = 30; // [0:255]
    _config.brightnessAutoMinNight = 0; // [0:255]
    _config.brightnessMax = 255; // [0:255]
    _config.color[0] = 255; // R
    _config.color[1] = 255; // G
    _config.color[2] = 255; // B
    _config.color[3] = 255; // W
    _config.mode = 1;
    _config.animation = 0;
    _config.animSpeed = 10;
    _config.animBrightnessMin = 10;
    _config.animBrightnessMax = 100;
    _config.ledConfig = 0;
    _config.ledType = LED_TYPE_DEFAULT; // WS2812 / WS2813
    _config.luxSensitivity = 40;
    _config.language = 0;

    _config.MQTTServer = "";
    _config.MQTTLogin = "";
    _config.MQTTPassword = "";
    _config.MQTTPort = 1883;
    _config.MQTTPubInterval = 120; // in sec

    WriteConfig();

    // ReadConfig() does this on the normal path; the defaults path needs it too,
    // otherwise the animation parameters stay at zero and every animation stalls.
    syncLiveFromConfig();
  }

  // Start led strip
  QTLed.begin(); // Must be called after Serial.begin() and EEPROM configuration

  // Start RTC
  RTC.Begin();
  RTC.Enable32kHzPin(false);
  RTC.SetSquareWavePin(DS3231SquareWavePin_ModeNone);
  handleTimeFromRTC();
  updateTime();

  //  Connect to WiFi access point or start as Access point
  // Connect the ESP8266 to local WIFI network in Station mode
  //printConfig();

  // Configure WiFi
  WiFiMgr.setAPssid("TexTime-" + String(ESP.getChipId(), HEX));

  if (!_config.dhcp)
  {
    WiFiMgr.setSTAIPip(IPAddress(_config.IP[0], _config.IP[1], _config.IP[2], _config.IP[3]),
      IPAddress(_config.Gateway[0], _config.Gateway[1], _config.Gateway[2], _config.Gateway[3]),
      IPAddress(_config.Netmask[0], _config.Netmask[1], _config.Netmask[2], _config.Netmask[3]),
      IPAddress(_config.DNS[0], _config.DNS[1], _config.DNS[2], _config.DNS[3]));
  }

  // Start WiFi
  WiFiMgr.tryToConnect(_config.ssid, _config.password, _config.DeviceName);

  // Start HTTP Server for configuration
  // Serves the page only; configuration is written through /admin/save/*.
  _server.on("/", []() {
    _server.send_P(200, "text/html", PAGE_index);
  });

  _server.on("/index.html", []() {
    //Serial.println("index.html");
    _server.send_P(200, "text/html", PAGE_index);
  });

  _server.on("/favicon.ico", []() {
    //Serial.println("favicon.ico");
    _server.send_P(200, "image/png", PAGE_ico, PAGE_ico_size);
  });

  _server.on("/apple-touch-icon.png", []() {
    //Serial.println("favicon.ico");
    _server.send_P(200, "image/png", PAGE_ico, PAGE_ico_size);
  });

  _server.on("/style.css", []() {
    //Serial.println("style.css");
    _server.sendHeader("Cache-Control", "max-age=3600");
    _server.send_P(200, "text/css", PAGE_style_css);
  });

  _server.on("/microajax.js", []() {
    //Serial.println("microajax.js");
    _server.sendHeader("Cache-Control", "max-age=3600");
    _server.send_P(200, "application/javascript", PAGE_microajax_js);
  });

  _server.on("/description.xml", HTTP_GET, [](){
    SSDP.schema(_server.client());
  });

  _server.on("/admin/networkfieldsvalues", send_network_configuration_values_html);
  _server.on("/admin/networkconnectionvalues", send_network_connection_values_html);
  _server.on("/admin/mqttfieldsvalues", send_mqtt_configuration_values_html);
  _server.on("/admin/mqttconnectionvalues", send_mqtt_connection_values_html);
  _server.on("/admin/infovalues", send_information_configuration_values_html);
  _server.on("/admin/ntpfieldsvalues", send_ntp_configuration_values_html);
  _server.on("/admin/generalfieldsvalues", send_general_configuration_values_html);
  _server.on("/admin/generallangsvalues", send_general_langs_values_html);
  _server.on("/admin/generalmodesvalues", send_general_modes_values_html);
  _server.on("/admin/generalanimationsvalues", send_general_animations_values_html);
  _server.on("/admin/generalledconfigvalues", send_general_ledconfig_values_html);
  _server.on("/admin/generalledtypevalues", send_general_ledtype_values_html);

  _server.on("/admin/langvalue", send_lang_value_html);
  _server.on("/admin/led", send_general_led);

  _server.on("/tetris.html", send_tetris_html);
  _server.on("/admin/tetris", send_tetris_action);
  _server.on("/admin/tetrisstate", send_tetris_state);

  _server.on("/snake.html", send_snake_html);
  _server.on("/admin/snake", send_snake_action);
  _server.on("/admin/snakestate", send_snake_state);

  // Async save endpoints
  _server.on("/admin/save/general", HTTP_POST, []() {
    if (_server.args() > 0) {
      // Process general settings save
      //
      // "brightnessauto" is a checkbox, and an unticked checkbox is simply
      // absent from the request -- indistinguishable from a form that was
      // submitted before its values finished loading. Only trust the absence
      // when the page states it really did send the form.
      if (_server.hasArg("formready"))
        _config.brightnessAuto = false;

      for (uint8_t i = 0; i < _server.args(); i++) {
        if (_server.argName(i) == "brightnessauto") _config.brightnessAuto = true;
        if (_server.argName(i) == "brightness") _config.brightness = _server.arg(i).toInt();
        if (_server.argName(i) == "brightnessday") _config.brightnessAutoMinDay = _server.arg(i).toInt();
        if (_server.argName(i) == "brightnessnight") _config.brightnessAutoMinNight = _server.arg(i).toInt();
        if (_server.argName(i) == "brightnessmax") _config.brightnessMax = constrain(_server.arg(i).toInt(), 1, 255);
        if (_server.argName(i) == "color") {
          String colorStr = _server.arg(i);
          // Remove # if present
          if (colorStr.startsWith("#")) {
            colorStr = colorStr.substring(1);
          }
          // An empty field parses as 0, which is black. That is never what the
          // user meant; it means the form had nothing to send yet.
          if (colorStr.length() > 0) {
            int32_t l = strtol(colorStr.c_str(), 0, 16);
            _config.color[0] = (l >> 16) & 0xFF;
            _config.color[1] = (l >> 8) & 0xFF;
            _config.color[2] = (l >> 0) & 0xFF;
          }
        }
        if (_server.argName(i) == "lang") _config.language = _server.arg(i).toInt();
        if (_server.argName(i) == "mode") _config.mode = _server.arg(i).toInt();
        if (_server.argName(i) == "animation") _config.animation = _server.arg(i).toInt();
        if (_server.argName(i) == "colorrandom") _config.colorRandom = _server.arg(i).toInt();
        if (_server.argName(i) == "ledconfig") _config.ledConfig = _server.arg(i).toInt();
        if (_server.argName(i) == "ledtype") _config.ledType = sanitizeLedType(_server.arg(i).toInt());
        if (_server.argName(i) == "brightnesssensibility") _config.luxSensitivity = constrain(_server.arg(i).toInt(), 1, 255);
        if (_server.argName(i) == "animspeed") _config.animSpeed = constrain(_server.arg(i).toInt(), 1, 20);
        if (_server.argName(i) == "animbrightmin") _config.animBrightnessMin = constrain(_server.arg(i).toInt(), 0, 100);
        if (_server.argName(i) == "animbrightmax") _config.animBrightnessMax = constrain(_server.arg(i).toInt(), 0, 100);
      }

      // Same range rule as on the EEPROM read path, so what is stored can never
      // differ from what a reboot would accept.
      validateAnimBrightness();

      WriteConfig();

      QTLed.begin();

      // The user settings now win over any scheduler slot override still active.
      QTLed.applyUserSettings();
      
      _server.send(200, "text/plain", "OK");
    } else {
      _server.send(400, "text/plain", "ERROR");
    }
  });
  
  _server.on("/admin/save/network", HTTP_POST, []() {
    if (_server.args() > 0) {
      // Validate the static addresses before touching anything. This handler
      // reboots the device on its way out, so writing a half-parsed address
      // means coming back on one that cannot connect, with the setup access
      // point as the only way in.
      if (!_server.hasArg("dhcp")) {
        static const char *addrFields[] = { "ipaddress", "netmask", "gateway", "dnsserver" };
        for (uint8_t f = 0; f < 4; f++) {
          if (!_server.hasArg(addrFields[f])) continue;
          if (!isValidIPv4(_server.arg(addrFields[f]))) {
            _server.send(400, "text/plain", "BAD_ADDRESS");
            return;
          }
        }
      }

      bool openWifi = false;

      _config.dhcp = false;
      for (uint8_t i = 0; i < _server.args(); i++) {
        if (_server.argName(i) == "ssid") _config.ssid = _server.arg(i);
        if (_server.argName(i) == "password") { String p = _server.arg(i); if (p.length() > 0) _config.password = p; }
        if (_server.argName(i) == "openwifi") openWifi = true;
        if (_server.argName(i) == "ipaddress") {
          // Parse IP address string like "192.168.1.100"
          String ip = _server.arg(i);
          int parts[4];
          int partIndex = 0;
          int start = 0;
          int len_ip = ip.length();
          for (int j = 0; j <= len_ip && partIndex < 4; j++) {
            if (j == len_ip || ip.charAt(j) == '.') {
              String part = ip.substring(start, j);
              parts[partIndex] = part.toInt();
              if (checkRange(String(parts[partIndex]))) {
                _config.IP[partIndex] = parts[partIndex];
              }
              partIndex++;
              start = j + 1;
            }
          }
        }
        if (_server.argName(i) == "netmask") {
          // Parse netmask string
          String nm = _server.arg(i);
          int parts[4];
          int partIndex = 0;
          int start = 0;
          int len_nm = nm.length();
          for (int j = 0; j <= len_nm && partIndex < 4; j++) {
            if (j == len_nm || nm.charAt(j) == '.') {
              String part = nm.substring(start, j);
              parts[partIndex] = part.toInt();
              if (checkRange(String(parts[partIndex]))) {
                _config.Netmask[partIndex] = parts[partIndex];
              }
              partIndex++;
              start = j + 1;
            }
          }
        }
        if (_server.argName(i) == "gateway") {
          // Parse gateway string
          String gw = _server.arg(i);
          int parts[4];
          int partIndex = 0;
          int start = 0;
          int len_gw = gw.length();
          for (int j = 0; j <= len_gw && partIndex < 4; j++) {
            if (j == len_gw || gw.charAt(j) == '.') {
              String part = gw.substring(start, j);
              parts[partIndex] = part.toInt();
              if (checkRange(String(parts[partIndex]))) {
                _config.Gateway[partIndex] = parts[partIndex];
              }
              partIndex++;
              start = j + 1;
            }
          }
        }
        if (_server.argName(i) == "dnsserver") {
          // Parse DNS string
          String dns = _server.arg(i);
          int parts[4];
          int partIndex = 0;
          int start = 0;
          int len_dns = dns.length();
          for (int j = 0; j <= len_dns && partIndex < 4; j++) {
            if (j == len_dns || dns.charAt(j) == '.') {
              String part = dns.substring(start, j);
              parts[partIndex] = part.toInt();
              if (checkRange(String(parts[partIndex]))) {
                _config.DNS[partIndex] = parts[partIndex];
              }
              partIndex++;
              start = j + 1;
            }
          }
        }
        if (_server.argName(i) == "dhcp") _config.dhcp = true;
        if (_server.argName(i) == "devicename") _config.DeviceName = _server.arg(i);
      }

      // An empty password field means "unchanged", so joining an open network
      // needs an explicit opt-in. It wins over whatever the field contains.
      if (openWifi) _config.password = "";

      WriteConfig();
      _server.send(200, "text/plain", "OK");
      ESP.restart();
    } else {
      _server.send(400, "text/plain", "ERROR");
    }
  });
  
  _server.on("/admin/save/ntp", HTTP_POST, []() {
    // Every field here has a harmful default: the timezone list starts at
    // GMT-12, the server name is empty, and an unticked Daylight saving box is
    // simply absent. A form submitted before its values arrived carries all
    // three, and the save is applied to the clock straight away. Only trust it
    // when the page states it really did fill the form in.
    if (!_server.hasArg("formready")) {
      _server.send(400, "text/plain", "NOT_READY");
      return;
    }

    if (_server.args() > 0) {
      _config.isDayLightSaving = false;
      for (uint8_t i = 0; i < _server.args(); i++) {
        if (_server.argName(i) == "ntpserver") _config.ntpServerName = _server.arg(i);
        if (_server.argName(i) == "update") _config.Update_Time_Via_NTP_Every = clampNtpInterval(_server.arg(i).toInt());
        if (_server.argName(i) == "tz") _config.timeZone = _server.arg(i).toInt();
        if (_server.argName(i) == "dst") _config.isDayLightSaving = true;
      }
      
      WriteConfig();
      getNTPtime();
      _server.send(200, "text/plain", "OK");
    } else {
      _server.send(400, "text/plain", "ERROR");
    }
  });
  
  _server.on("/admin/save/mqtt", HTTP_POST, []() {
    // An empty broker address and a port of 0 are what a form submitted before
    // its values arrived carries, and saving them stops MQTT without a word.
    // Only trust the form when the page states it really did fill it in.
    if (!_server.hasArg("formready")) {
      _server.send(400, "text/plain", "NOT_READY");
      return;
    }

    if (_server.args() > 0) {
      for (uint8_t i = 0; i < _server.args(); i++) {
        if (_server.argName(i) == "host") _config.MQTTServer = _server.arg(i);
        if (_server.argName(i) == "port") _config.MQTTPort = _server.arg(i).toInt();
        if (_server.argName(i) == "login") _config.MQTTLogin = _server.arg(i);
        // Unlike the WiFi one, this password is sent back to the page, so the
        // field arrives filled and an empty one means the user cleared it.
        if (_server.argName(i) == "mqttpassword") _config.MQTTPassword = _server.arg(i);
        if (_server.argName(i) == "interval") _config.MQTTPubInterval = _server.arg(i).toInt();
      }
      
      WriteConfig();
      _mqtt.disconnect();
      _mqtt.setServer(_config.MQTTServer.c_str(), _config.MQTTPort);
      _server.send(200, "text/plain", "OK");
    } else {
      _server.send(400, "text/plain", "ERROR");
    }
  });


  _server.onNotFound([]() {
    Serial.println("Page Not Found");
    _server.send(400, "text/html", "Page not Found");
  });

  _server.on("/admin/schedulerconfig", send_scheduler_config);
  _server.on("/admin/schedulerdata", send_scheduler_data);
  _server.on("/admin/save/schedulerbulk", HTTP_POST, save_scheduler_bulk);
  _server.on("/admin/scheduler/apply", HTTP_POST, apply_scheduler_now);
  _server.on("/admin/save/schedulerenabled", HTTP_POST, save_scheduler_enabled);

  _httpUpdater.setup(&_server);
  _server.begin();
  Serial.println("HTTP server started");

  // ***********  OTA SETUP
  //ArduinoOTA.setHostname(host);
  ArduinoOTA.onStart([]() { // what to do before OTA download insert code here
    Serial.println("Start");
  });
  ArduinoOTA.onProgress([](unsigned int progress, unsigned int total) {
    Serial.printf("Progress: %u%%\r", (progress / (total / 100)));
  });
  ArduinoOTA.onEnd([]() {
    Serial.println("\nEnd");
    ESP.restart();
  });

  ArduinoOTA.onError([](ota_error_t error) {
    Serial.printf("Error[%u]: ", error);
    if (error == OTA_AUTH_ERROR) Serial.println("Auth Failed");
    else if (error == OTA_BEGIN_ERROR) Serial.println("Begin Failed");
    else if (error == OTA_CONNECT_ERROR) Serial.println("Connect Failed");
    else if (error == OTA_RECEIVE_ERROR) Serial.println("Receive Failed");
    else if (error == OTA_END_ERROR) Serial.println("End Failed");
    ESP.restart();
  });

  /* setup the OTA server */
  ArduinoOTA.begin();

  MDNS.begin(_config.DeviceName.c_str());
  MDNS.addService("http", "tcp", 80);

  NBNS.begin(_config.DeviceName.c_str());

  LLMNR.begin(_config.DeviceName.c_str());

  SSDP.setSchemaURL("description.xml");
  SSDP.setHTTPPort(80);
  SSDP.setName(_config.DeviceName);
  SSDP.setSerialNumber(String(ESP.getFlashChipId()));
  SSDP.setURL("index.html");
  SSDP.setModelName("TexTime");
  SSDP.setModelNumber("Build : " + printDateTime(RtcDateTime(__DATE__, __TIME__)));
  SSDP.setModelURL("https://github.com/psykokwak-com/TexTime");
  SSDP.setManufacturer("TexTime");
  SSDP.setManufacturerURL("https://github.com/psykokwak-com/TexTime");
  SSDP.setDeviceType("upnp:rootdevice");
  SSDP.begin();

  // MQTT configuration
  if (_config.MQTTPubInterval < 1) _config.MQTTPubInterval = 1;
  _mqttWifiClient.setNoDelay(true);
  _mqttWifiClient.setTimeout((unsigned long)MQTT_SOCKET_TIMEOUT * 1000UL);
  _mqtt.setServer(_config.MQTTServer.c_str(), _config.MQTTPort);
  _mqtt.setCallback(mqttCallback);

  QTLed.applyUserSettings();

  Serial.println("Ready");


  //**** Normal Sketch code here...


}


// the loop function runs over and over again forever
void loop() {

  // Handle WiFi AP/STA
  if (WiFiMgr.handle()) {
    getNTPtime();
  }

  // Update time from RTC
  handleTimeFromRTC();

  // Handle NTP receive packets
  handleNTPRequest();

  // Update time
  handleISRsecondTick();

  // Read current light value
  handleAmbientLightSensor();

  // OTA request handling
  ArduinoOTA.handle();

  // WebServer requests handling
  _server.handleClient();

  // DNS requests handling 
  //_dnsServer.processNextRequest();

  // MQTT
  mqttReconnect();
  _mqtt.loop();
  mqttPollingPublisher();

  // Hand the display back if a controller page went away without saying so
  QTLed.handleGameTimeout();

  // Handle led display
  handleScheduler();
  QTLed.handle();

  // For debug purpose only
  toggleLed(_timestamp);
}

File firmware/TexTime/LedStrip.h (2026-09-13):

//
// Led Strip configuration for TexTime
//

#include "fonts.h"
#include "textime.h"

#define NROW 10
#define NCOL 11
#define NEDGE 4

#define pVOID  Pixel()
#define pBLACK Pixel(RgbColor(0  ,   0,   0))
#define pRED   Pixel(RgbColor(255,   0,   0))
#define pGREEN Pixel(RgbColor(0  , 255,   0))
#define pBLUE  Pixel(RgbColor(0  , 0  , 255))
#define pWHITE Pixel(RgbColor(255, 255, 255))

// NeoPixelBus fixes the LED protocol and the colour order at compile time, in
// its template arguments. The LED type is a setting here, so the strip is
// driven through this small interface and each supported type is one
// instantiation of NeoPixelBusLg behind it. Only one exists at a time.
class LedBus
{
public:
  virtual ~LedBus() {}
  virtual void Begin() = 0;
  virtual void Show() = 0;
  virtual bool CanShow() = 0;
  virtual uint16_t PixelCount() = 0;
  virtual void ClearTo(const RgbColor &color) = 0;
  virtual void SetPixelColor(uint16_t index, const RgbColor &color) = 0;
  virtual void SetLuminance(uint8_t luminance) = 0;
  virtual uint8_t GetLuminance() = 0;
};

// The whole program thinks in RgbColor; this is where a colour becomes what
// the strip actually takes. On an RGB strip that is the colour itself.
template<typename T_COLOR>
struct BusColorFrom
{
  static T_COLOR convert(const RgbColor &c)
  {
    return T_COLOR(c);
  }
};

// On an RGBW strip the part the three colours have in common is white, and
// the strip has a LED made for that: it is moved onto the white channel and
// taken out of the other three. Pure white text lights only the white LED --
// cleaner, brighter, and cheaper in current than mixing it from red, green
// and blue. Anything left over after the move is the tint, and stays on the
// colour LEDs. (RgbwColor's own conversion would leave W at zero.)
template<>
struct BusColorFrom<RgbwColor>
{
  static RgbwColor convert(const RgbColor &c)
  {
    uint8_t w = c.R;
    if (c.G < w) w = c.G;
    if (c.B < w) w = c.B;

    return RgbwColor(c.R - w, c.G - w, c.B - w, w);
  }
};

// NeoPixelBrightnessBus is deprecated in favour of NeoPixelBusLg. The third
// template argument is NeoGammaNullMethod because NeoPixelBusLg applies gamma
// correction by default, which would change every colour on the strip; the null
// method keeps the exact output this project has always had.
template<typename T_FEATURE, typename T_METHOD>
class LedBusImpl : public LedBus
{
private:
  // The feature's colour object: RgbColor on an RGB strip, RgbwColor on an
  // RGBW one. BusColorFrom does the conversion, white extraction included.
  typedef typename T_FEATURE::ColorObject BusColor;
  typedef BusColorFrom<BusColor> Convert;

  NeoPixelBusLg<T_FEATURE, T_METHOD, NeoGammaNullMethod> _bus;

public:
  LedBusImpl(uint16_t countPixels, uint8_t pin)
    : _bus(countPixels, pin)
  {
  }

  void Begin() { _bus.Begin(); }
  void Show() { _bus.Show(); }
  bool CanShow() { return _bus.CanShow(); }
  uint16_t PixelCount() { return _bus.PixelCount(); }
  void ClearTo(const RgbColor &color) { _bus.ClearTo(Convert::convert(color)); }
  void SetPixelColor(uint16_t index, const RgbColor &color) { _bus.SetPixelColor(index, Convert::convert(color)); }
  void SetLuminance(uint8_t luminance) { _bus.SetLuminance(luminance); }
  uint8_t GetLuminance() { return _bus.GetLuminance(); }
};

template<typename T_FEATURE, typename T_METHOD>
LedBus *createLedBus(uint16_t countPixels, uint8_t pin)
{
  return new LedBusImpl<T_FEATURE, T_METHOD>(countPixels, pin);
}

// The LED types the configuration page offers. The index into this table is
// what the EEPROM stores, so entries are only ever appended: reordering or
// removing one would silently change the strip type of every clock out there.
// Entry 0 is what every clock built so far runs on, and what an EEPROM that
// predates the setting falls back to (LED_TYPE_DEFAULT in global.h).
//
// All of them go through UART1 on D4: DMA would need GPIO3, which the USB
// serial bridge already owns.
struct LedType
{
  const char *name;
  LedBus *(*create)(uint16_t countPixels, uint8_t pin);
};

static const LedType LED_TYPES[] = {
  { "WS2812 / WS2813 (GRB)", createLedBus<NeoGrbFeature,  NeoEsp8266Uart1Ws2813Method> },
  { "WS2812 / WS2813 (RGB)", createLedBus<NeoRgbFeature,  NeoEsp8266Uart1Ws2813Method> },
  { "SK6812 (GRB)",          createLedBus<NeoGrbFeature,  NeoEsp8266Uart1Sk6812Method> },
  { "SK6812 (GRBW)",         createLedBus<NeoGrbwFeature, NeoEsp8266Uart1Sk6812Method> },
  { "SK6812 (RGBW)",         createLedBus<NeoRgbwFeature, NeoEsp8266Uart1Sk6812Method> },
  { "WS2811 (RGB)",          createLedBus<NeoRgbFeature,  NeoEsp8266Uart1Ws2811Method> },
  { "WS2811 (BRG)",          createLedBus<NeoBrgFeature,  NeoEsp8266Uart1Ws2811Method> },
  { "APA106 (RGB)",          createLedBus<NeoRgbFeature,  NeoEsp8266Uart1Apa106Method> },
};

// Declared in global.h, so the config code can range-check a stored index
// without seeing the table.
int ledTypesCount()
{
  return sizeof(LED_TYPES) / sizeof(LED_TYPES[0]);
}


class Pixel
{
public:
  RgbColor color;
  bool display;

  Pixel()
    : color(RgbColor(0, 0, 0))
    , display(false)
  {
  }

  Pixel(const RgbColor &c)
  {
    color = c;
    display = true;
  }
};

class PixelsArray {
private:
  Pixel _pixels[NROW][NCOL];

public:
  PixelsArray()
  {
    clear();
  }

  void fill(const Pixel &p)
  {
    for (int i = 0; i < NROW; i++)
    {
      for (int j = 0; j < NCOL; j++)
      {
        _pixels[i][j] = p;
      }
    }
  }

  void clear()
  {
    fill(pVOID);
  }

  void setPixel(const Pixel &p, int row, int col)
  {
    if (row < 0) return;
    if (col < 0) return;
    if (row > NROW - 1) return;
    if (col > NCOL - 1) return;

    _pixels[row][col] = p;
  }

  Pixel getPixel(int row, int col)
  {
    if (row < 0) return pVOID;
    if (col < 0) return pVOID;
    if (row > NROW - 1) return pVOID;
    if (col > NCOL - 1) return pVOID;

    return _pixels[row][col];
  }
};

struct PixelsContainer
{
  PixelsArray pixelsArray;
  Pixel pixelsEdge[NEDGE];
  bool hasChanged;
};



class LedConfiguration {
public:
  virtual int ledsByPixelForMatrix() = 0;
  virtual int ledsByPixelForEdges() = 0;
  virtual int ledsNumber() = 0;
  virtual String getName() = 0;
  virtual const uint16_t *getLedsMatrixId(int row, int col) = 0;
  virtual const uint16_t *getLedsEdgeId(int n) = 0;
  virtual ~LedConfiguration() {}
};
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

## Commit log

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2019-06-05 * Bugfix : wrong eeprom mqtt fields initialization in case of an update
    [global.h]
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2020-01-04 Fix a bug that crashs some ws2813 randomly. Improve signal timing quality.
    [LedStrip.h, TexTime.ino]
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2026-05-16 Add games (Tetris, Snake), 5 new animations, and multiple bugfixes
    New features:
    - Page_tetris.h: Tetris game playable via web interface on LED matrix
    - Page_snake.h: Snake game playable via web interface on LED matrix
    - LedStrip.h: 5 new animations + improvements to existing ones
    Bug fixes:
    - global.h: EEPROM reset now covers full 1024 bytes (was 511); off-by-one
    in ReadStringFromEEPROM; WriteStringToEEPROM truncates to maxLen; passwords
    masked in printConfig; add AP_DEFAULT_PASSWORD, EEPROM_SIZE constants;
    add brightnessMax, APPassword, animSpeed/Min/Max fields with EEPROM R/W;
    timezone sanity check on ReadConfig
    - WiFiMgr.h: timers unsigned int -> unsigned long (overflow fix at ~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
    [LedStrip.h, NTP.h, TexTime.ino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]
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2026-05-16 Fix NTP timezone calculation (regression: 3600 -> 360 multiplier)
    The timezone select uses 1/10th-hour units (GMT+1 = value 10).
    Correct multiplier is 360 (10 * 360 = 3600s = 1h).
    The (long) cast is kept to prevent int overflow for UTC+9 and above.
    [NTP.h]
2026-05-16 Fix: add bounds validation for animation EEPROM value
    Prevents setAnimation() from silently falling back to index 0 (Normal)
    when EEPROM contains an out-of-range animation value (e.g. 0xFF on first
    boot or after firmware downgrade).
    [global.h]
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2026-05-16 Fix: Matrix trail fade proportional to animBrightnessMax
    Replace absolute Darken(35) with a distance-based proportional fade so
    the tail remains visible at any brightness level. Previously, low
    animBrightnessMax values caused the trail to reach black in 2-3 pixels,
    making variable trail lengths invisible.
    [LedStrip.h]
2026-05-16 Fix: Lightning flash no longer overwrites time display words
    Add copyForeground() at the end of the FLASH phase, consistent with
    BUILD and FADE which already do this. Background pixels still flash
    white but word pixels are restored on top.
    [LedStrip.h]
2026-05-16 Feat: custom HSV color picker replaces native <input type="color">
    Replaces browser-native color picker with a custom inline picker:
    - Colored swatch (click to open/close)
    - 2D saturation/value square (drag to pick)
    - Hue rainbow slider
    - Hex text input stays for direct entry
    - Works identically on Android and desktop
    - CSS loaded with ?t=timestamp to prevent stale cache
    Fixes Android Chrome "Personnalise" HSV sliders defaulting to 0,0,0.
    [Page_style.css.h]
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2026-08-25 Fix blocking regressions and pre-merge issues from PR #9
    Restore what the PR removed:
    - LedConfiguration40x40 back to the standard pixel mapping (the PR shipped a
    contributor-specific wiring and commented the original out)
    - LedConfiguration100x100_3 re-registered (index 3 silently fell back to
    index 2, driving 244 LEDs instead of 262)
    - LED index tables back to uint16_t (uint8_t capped the design at 255 LEDs,
    which is what forced 100x100_3 out)
    - Ripple and MinuteFall animations restored at indices 8 and 9, the five new
    ones appended at 10-14, so saved animation indices keep their meaning
    Fixes:
    - Scheduler no longer writes _config: slot overrides go to a new _animParams
    struct,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
    [LedStrip.h, Page_scheduler.h, TexTime.ino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]
2026-08-25 Set WiFi STA connection timeout to 15s
    PR #9 raised it from 10s to 30s. 10s was too short (scan, association, WPA2
    handshake and DHCP lease can legitimately exceed it and cause spurious AP
    fallbacks, each costing 10 minutes offline), but 30s makes first-time setup
    needlessly slow. 15s is the middle ground.
    [WiFiMgr.cpp]
2026-08-25 Silence -Wreorder in the Snake animation constructor
    Members are initialised in declaration order regardless of the initialiser
    list, and every initialiser here is a constant, so behaviour was already
    correct. Reordering the list to match just removes the build warning.
    [LedStrip.h]
2026-08-25 Fix deprecation and sign-compare warnings
    Rtc_by_Makuna deprecated Epoch32Time()/InitWithEpoch32Time() in favour of
    Unix32Time()/InitWithUnix32Time(). The replacements have byte-identical
    bodies, so this is a pure rename.
    The four IP parsing loops in the network save handler compared an int
    counter against String::length() (unsigned int). Hoisting the length into
    an int is clearer than casting at both comparison sites. These loops come
    from master, not from PR #9.
    [NTP.h, TexTime.ino]
2026-08-25 Migrate NeoPixelBrightnessBus to NeoPixelBusLg
    NeoPixelBrightnessBus is deprecated. NeoPixelBusLg is a drop-in replacement
    apart from SetBrightness/GetBrightness becoming SetLuminance/GetLuminance,
    and gamma correction being applied by default -- NeoGammaNullMethod is passed
    as the third template argument to keep the exact colour output this project
    has always produced.
    The behavioural difference is an improvement: NeoPixelBrightnessBus rescaled
    the entire pixel buffer in place on every SetBrightness() call, so the
    automatic brightness loop degraded colour precision between two redraws.
    NeoPixelBusLg keeps pixels at full precision and applies luminance on write.
    Kept as an isolated commit: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
    [LedStrip.h, TexTime.ino]
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2026-08-25 Decouple game brightness from the animation settings
    Games rendered their colours through animBrightnessMax, an ambient-decoration
    style parameter, on top of the strip-level brightness. The two multiplied:
    with animBrightnessMax at 20%, a settled Tetris block came out at 19/255
    before the automatic brightness loop dimmed it further.
    Games now render at full intensity and are dimmed only by the strip
    brightness (automatic or manual), which is the mechanism that actually
    answers "how bright should my clock be". Tetris keeps its settled-versus-
    falling contrast as a fixed 1:2 ratio instead of a /512 constant that broke
    down at the bottom of the scale.
    Also freeze the scheduler while a game is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
    [LedStrip.h, Page_scheduler.h]
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2026-08-25 Hand the display back when a game's controller page goes away
    Closing the tab, locking the phone or losing the WiFi left the clock stuck on
    a frozen board forever: tetrisStop()/snakeStop() were only ever reached from
    the Back to clock button. Freezing the scheduler during a game made it worse,
    since a slot boundary could no longer take the mode back either.
    Two layers, applied to both games:
    - The pages fire an exit on pagehide via sendBeacon, the only request that
    survives page teardown. A page parked in the back/forward cache is left
    alone (it may come back) and refreshes its state on pageshow.
    - gameKeepAlive() timestamps every request from a game endpoint -- the pages
    already pol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
    [LedStrip.h, TexTime.ino, global.h]
2026-08-25 Make a luminance change reach the strip immediately
    NeoPixelBusLg applies the luminance while a pixel is written, not at Show()
    time, and SetLuminance() deliberately leaves the existing buffer untouched --
    verified in the library source and confirmed independently against the render
    loop. A bare SetLuminance()+Show() therefore transmitted nothing: the new
    level only appeared at the next content redraw, which is the next minute in
    Time mode and the next day in Day mode. Both are the default configuration.
    Master got away with the same firmware structure only because the old
    NeoPixelBrightnessBus rescaled the buffer and dirtied it itself; the library
    swap in d957a2d removed the only thing push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
    [LedStrip.h]
2026-08-25 Stop the WiFi and MQTT password fields overwriting each other
    Both inputs carried name="password" while setValues dispatches by element id
    and FormData serialises by name, so the two secrets crossed in both
    directions. Opening the MQTT tab wrote the broker password into the WiFi
    password box, and saving the network form then replaced the WiFi credential
    with it -- the clock loses its network on the next boot. In the other
    direction nothing ever populated #mqttpassword, so saving the MQTT form
    posted an empty value and wiped the stored broker password.
    The MQTT field now uses its own argument name throughout: the input, the
    values endpoint and both save handlers (the modern POST route and th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
    [TexTime.ino]
2026-08-25 Remove the access point password entirely; the AP is open again
    PR #9 made the AP WPA2-protected with a hardcoded default. Back to master's
    behaviour: an open network, as the setup procedure and the hardware
    documentation describe it.
    Removed the config field and its EEPROM slot at 712, the default define, the
    form field and its two translations, the too-short rejection and its client
    side handling, the values endpoint entry, and restored setAPssid's default
    argument and the length == 0 test in setAPMode.
    [WiFiMgr.cpp, global.h]
2026-08-26 Stop the General form saving before its values have loaded
    The stored settings arrive on the last of five chained requests. Saving
    before that lands submitted defaults: an unticked Automatic brightness box
    is absent from the request, which the firmware read as a deliberate untick
    and wrote to flash, and the empty hidden colour field parsed as 0 -- black,
    also written. A failed request left the form armed indefinitely, since the
    chain had no catch.
    Client side: Save stays disabled until the chain resolves, the submit
    handler refuses early (Enter in a text field submits past a disabled
    button), and a failed load now says so instead of staying silent. The
    button is looked up by id because it s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
    [TexTime.ino]
2026-08-26 Only a player keeps a game alive, not an open tab
    The idle timeout added in b1c790e never fired. gameKeepAlive() was called as
    the first statement of all four game endpoints, before any check of which
    game was running or whether one was at all, and the state endpoints are
    polled every 400 ms by any open controller page. A forgotten Snake tab
    therefore refreshed the deadline of a live Tetris session, and the display
    stayed hostage for as long as that tab kept polling -- indefinitely if its
    window was visible rather than backgrounded.
    The state polls no longer touch the deadline. Only the action endpoints do,
    and only after confirming the game they name is the one running, so a key
    pressed on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
    [LedStrip.h]
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2026-08-26 Stop Tetris gravity dying at level 12
    800UL - level*70UL is unsigned arithmetic, so from level 12 -- 120 cleared
    lines -- it wrapped to about 4.29 billion instead of going negative, and
    max(100UL, ...) preferred that. Pieces stopped falling altogether, leaving
    only the manual soft drop, until millis() wrapped some 49 days later.
    Now the subtraction never goes below the intended 100 ms floor, which is
    reached at level 10 and held from there. The curve up to level 11 is
    unchanged. Snake's equivalent was already guarded; this was an isolated slip.
    [LedStrip.h]
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2026-08-26 Give a dropped WiFi link time to come back before falling back to AP
    _STAlastTry was assigned in exactly one place, when a connection is
    attempted, and never refreshed while the link was up. It therefore expired a
    few seconds after boot and stayed expired for good, so the first loop
    iteration that found WiFi.status() != WL_CONNECTED dropped straight to AP
    mode. No tolerance whatsoever, and setAutoReconnect(true) -- set on the line
    above -- never got an iteration in which to act. Any router reboot cost ten
    minutes off the network.
    The deadline now moves while the link holds, and there are two grace periods:
    15 s before the clock has ever been on the network, where offering the setup
    access p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
    [WiFiMgr.cpp]
2026-08-26 Reject undersized and empty NTP replies
    handleNTPRequest() took the first datagram to arrive on the port and read
    bytes 40..43 as the timestamp without checking anything. A reply shorter than
    a full NTP packet left those bytes at the zero the buffer had been memset to
    before sending, and 0 - 2208988800 wraps to February 2036. The unixTime > 0
    guard accepts that, so the bogus date was stored and written into the DS3231,
    where it survives a reboot until a good sync happens to land.
    Replies shorter than NTP_PACKET_SIZE are now discarded, and a transmit
    timestamp at or below the epoch offset is rejected before the subtraction can
    wrap. Normal replies are unaffected.
    Not an attack scenario on a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
    [NTP.h]
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2026-08-26 Switch to and from summer time at the right hour
    Two errors compounded, both pushing the same way. summerTime() documents its
    input as UTC but adjustTimeZone() called it after adding the timezone offset,
    and the threshold in the rule read 3 where the EU rule is 01:00 UTC. In CET
    the change therefore landed at 03:00 local instead of 02:00 -- an hour of
    wrong time, twice a year, on a Sunday at dawn.
    The rule is now evaluated on UTC before the offset is applied, which is also
    what makes it correct for any configured timezone: the EU switches
    simultaneously across the union, not at 02:00 in each local time.
    The last-Sunday computation itself was always right; only the hour was wrong.
    Checked a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
    [NTP.h]
2026-08-26 Refuse an incomplete IP address instead of rebooting onto a broken one
    The address parsers split on dots and call toInt() on each piece, and toInt()
    answers 0 for an empty piece. An empty or truncated field therefore set the
    first octet to 0 and left the other three alone -- 192.168.1.100 became
    0.168.1.100 -- and this handler reboots on its way out, so the clock came
    back on an address that cannot connect, reachable only through the setup
    access point. checkRange() did not catch it because 0 is in range.
    Static addresses are now validated before anything is written: four decimal
    parts, each 0-255, nothing else. A bad one rejects the whole request with a
    message and changes nothing. Only ch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
    [TexTime.ino, global.h]
2026-08-26 Bound the NTP resync interval
    The interval was stored exactly as typed, with no check anywhere. At zero or
    below, the "time to resync?" test in getNTPtime() is true on every pass, so
    the clock would hammer a public NTP pool thousands of times a second --
    starving loop(), making the display stutter and earning a ban. Reachable by a
    typo in the form, and also through the legacy root route, which writes
    configuration straight from URL parameters.
    Clamped between one minute and one week on both write paths and on the EEPROM
    read, so a value that got stored before this is corrected at the next boot
    however it arrived there. Same shape as the timezone sanity check next to it.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
    [TexTime.ino, global.h]
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2026-08-26 Notice when the battery-backed clock cannot be trusted
    The library answers 1 January 2000 when it cannot read the DS3231, and
    records why in flags nothing ever consulted. A failed read was therefore
    adopted as the time. The same went for the oscillator-stop flag, which is
    exactly what a flat backup cell sets -- an unremarkable event on a clock that
    has been on the wall for a few years.
    handleTimeFromRTC() now checks IsDateTimeValid() and LastError() alongside
    GetIsRunning(), and keeps the time it already has rather than believing a bad
    read. The reason appears on the information page as Backup clock, so a cell
    that needs replacing shows up as a message instead of as odd behaviour.
    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
    [NTP.h]
2026-08-26 Drop the redundant second url-decode of the NTP server name
    urldecode() counted with a byte, so an input longer than 255 characters never
    terminated: the counter wrapped at 255 and started over, and the watchdog
    rebooted the clock. Reachable without any crafted request -- pasting a long
    string into the NTP server field was enough, which is what set it apart from
    the ten argument loops that share the same pattern but need 256 HTTP
    parameters to bite.
    The call was redundant anyway: ESP8266WebServer url-decodes both key and
    value while parsing (Parsing-impl.h:252-254), verified rather than assumed, so
    decoding again mangled any value containing a per cent sign. Both call sites
    now take the arg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
    [TexTime.ino, global.h]
2026-08-26 The root page no longer writes configuration from URL parameters
    Requesting / with parameters did not serve the page: it wrote configuration
    and, for the network case, rebooted. So http://textime/?brightness=1 was
    enough to reconfigure the clock, and fetching an address is something a page
    can make a browser do without being asked -- on a device with no
    authentication and an open firmware upload.
    Those four handlers also predate every check added since. The general one
    cleared the automatic brightness flag before even looking at the request,
    which is the defect fixed on the modern path in bb71ed8.
    Nothing used them. They were marked obsolete when the dashboard replaced
    them, the dashboard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
    [TexTime.ino]
2026-08-26 Handle the NTP era so time keeps working past February 2036
    NTP counts seconds since 1900 in 32 unsigned bits, which wraps on 7 February
    2036. The protocol anticipates this -- RFC 5905 calls the periods before and
    after an era -- but deliberately leaves the era number out of the packet: the
    client is expected to work it out from its own rough idea of the date. This
    client did not, it just subtracted a fixed offset.
    The previous commit's guard turned that into a graceful stop rather than a
    wrong date, but stopping was never necessary. The usual convention is the top
    bit of the seconds field: set for era 0, which runs from 1968 to the wrap,
    clear for era 1 after it. All zeroes still means an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
    [NTP.h]
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2026-08-26 Cleanup pass over the correction commits
    Quality only, no behaviour change. Four review passes -- reuse,
    simplification, efficiency, altitude -- and this is what survived triage.
    Memory, which is what matters here: 16.8 KB free was measured on the device.
    - The WiFi scan handler no longer assembles the network list before sending
    it. Each row is ~600 bytes, so fifteen networks needed one contiguous 8 KB
    block reached through hundreds of reallocations; it is now written straight
    to the client, peaking at one row. This is the cause the earlier streaming
    change only moved -- and String::concat fails silently, so running short
    showed as a truncated list, not an error.
    - The scheduler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
    [LedStrip.h, Page_scheduler.h, TexTime.ino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]
2026-08-26 Trim the comments down to what still constrains the code
    Comments were narrating how things used to be -- which divisor had drifted,
    what the old handler did, how many call sites a helper replaced. That belongs
    in the commit and in git blame, not above the code, where it describes
    something a reader cannot see and slowly stops matching.
    Seventeen such passages rewritten to state the constraint that still holds
    instead. "Every animation used to spell this out, which is exactly how the
    divisor drifted" becomes "one place, so the divisor cannot drift between
    animations": same warning to a future reader, no archaeology.
    Also shortened the four longest blocks, including the Tetris page header,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
    [LedStrip.h, NTP.h, WiFiMgr.cpp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]
2026-08-26 Stop a failed scheduler load turning into an erased schedule
    419e28a made the grid load once instead of on every tab focus, but set the
    "loaded" flag before the requests and gave the chain no catch. A failed load
    therefore looked like a finished one for ever -- the retry that switching
    tabs used to provide was exactly what that commit removed -- and Save then
    posted the empty grid. The firmware accepted it, wrote 0xFF over all 336
    slots, committed, and answered 200 with a green button.
    The one visual cue, the grid's Loading placeholder, is destroyed by the
    natural recovery gesture: New rule repaints a normal-looking blank week.
    Meanwhile the deliberate way to clear everything, RAZ, asks for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
    [Page_scheduler.h]
2026-08-26 A running game belongs to the device that started it
    Opening a controller page sent "start", the same action the Restart button
    sends. 4370d10 made that unconditional -- which was the point, Restart has to
    work mid-game -- and in doing so made merely opening Tetris on a phone reset
    a game somebody was playing on a tablet. Reloading was already covered by the
    pagehide exit; two separate devices were not.
    Opening a page now sends "attach", which starts a game if none is running and
    otherwise asks to join. The session is held by the device that started it, so
    a second page gets a read-only view: status reads "In use elsewhere", the
    controls are dimmed and inert, and Restart is disabled. Every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
    [LedStrip.h]
2026-08-26 Zero still means "never synchronise"
    323756d bounded the NTP interval between a minute and a week to stop a small
    value hammering a public pool. But zero was never that problem -- getNTPtime()
    tests it and skips the sync entirely, and the form says so in as many words:
    "seconds (0 = disabled)", with min="0".
    The clamp rewrote a stored zero to 60, so a clock deliberately kept off the
    network started querying a public pool every minute, for good, from the first
    boot after flashing. Typing 0 in the form appeared to save and then came back
    as 60, with no message: the field silently refused the value it advertises.
    Zero now passes through untouched on both write paths and on the EEPROM read;
    ev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
    [TexTime.ino, global.h]
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2026-08-26 Do not put an animation back over one chosen during a game
    A game saves the current animation index at start and restores it at the end.
    Nothing noticed when the animation changed in between, so a request made
    while playing -- from MQTT, or from the dashboard -- was silently undone when
    the game finished, and stayed undone until reboot.
    6ad82d0 made a mode change end the game, which looks like it should cover
    this, but changing the animation is not changing the mode and that path had
    no guard at all. Worse, the default mode is Time, which allows animations, so
    the game never forces a mode change and the common configuration is exactly
    the one that gets bitten. No second browser needed eithe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
    [LedStrip.h]
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2026-08-27 Guard the MQTT form, and stop leaking a poller on every save
    Last of the five save forms with no way to tell a filled-in form from one
    whose values never arrived. An empty broker address, a port of 0 and an
    interval of 0 are exactly what the untouched form carries, and saving them
    stops MQTT without a word -- nothing breaks, the clock carries on, and it
    surfaces the day an automation does not fire. Same marker as the other four.
    The other three forms were checked while here. General and Scheduler were
    already covered, and Network turns out to be covered too: an unloaded form
    has DHCP unticked, so the address validation looks at four empty fields and
    refuses. Incidental, but it holds for the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
    [TexTime.ino]
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
